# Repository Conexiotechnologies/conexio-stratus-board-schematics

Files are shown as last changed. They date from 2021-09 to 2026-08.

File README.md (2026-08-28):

# Conexio Stratus Cellular Board Design
Here you will find the schematic designs for the Conexio Stratus IoT dev kit based on nRF91xx series and the associated shields and the expansion dock.
A detailed description of the pin mapping can be found in each specific board directory.

## nRF9151 Conexio Stratus Pro Series

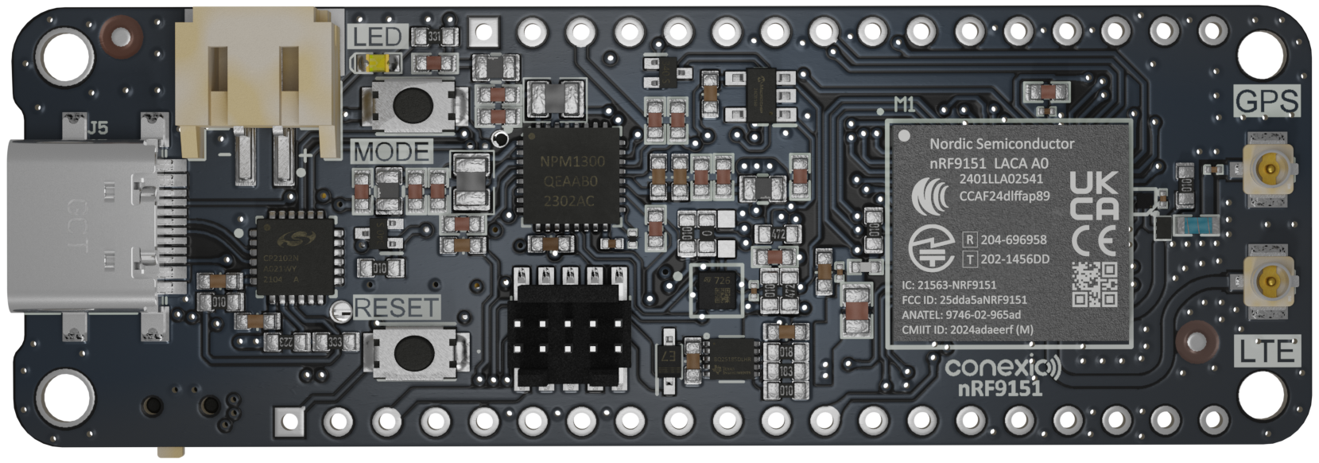
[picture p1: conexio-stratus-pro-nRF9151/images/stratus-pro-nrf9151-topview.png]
Stratus Pro - nRF9161/nRF9151


**Conexio Stratus Pro** is a tiny-yet-powerful development kit for creating cellular-connected electronic projects and products. Powered by the cutting-edge nRF9161 cellular modem from Nordic Semiconductor, Stratus Pro offers unparalleled versatility, reliability, and ease of use, making it the go-to solution for IoT developers worldwide. It is a battery-operated platform, making it ideal for prototyping cellular IoT systems, such as asset tracking, environmental monitoring, smart metering, and even industrial automation.

With LTE-M, NB-IoT, and GPS connectivity packed into a compact form factor, Stratus Pro ensures your devices stay connected in any environment. It enables real-time data transmission and location tracking with minimal power consumption. Future-proof your IoT projects with DECT NR+ readiness, ensuring compatibility with emerging cellular standards for enhanced performance and longevity.

## Built-In Battery Charging, Monitoring and Energy-Harvesting

Thanks to the nPM1300 PMIC and fuel gauge, you can remotely monitor your Stratus Pro’s battery vitals and charging status. Stratus Pro also has built-in charging circuitry that makes it easier to connect to and recharge the Li-Po battery, creating fully energy-autonomous applications.

## Conexio Stratus Pro nRF9151 Pinouts

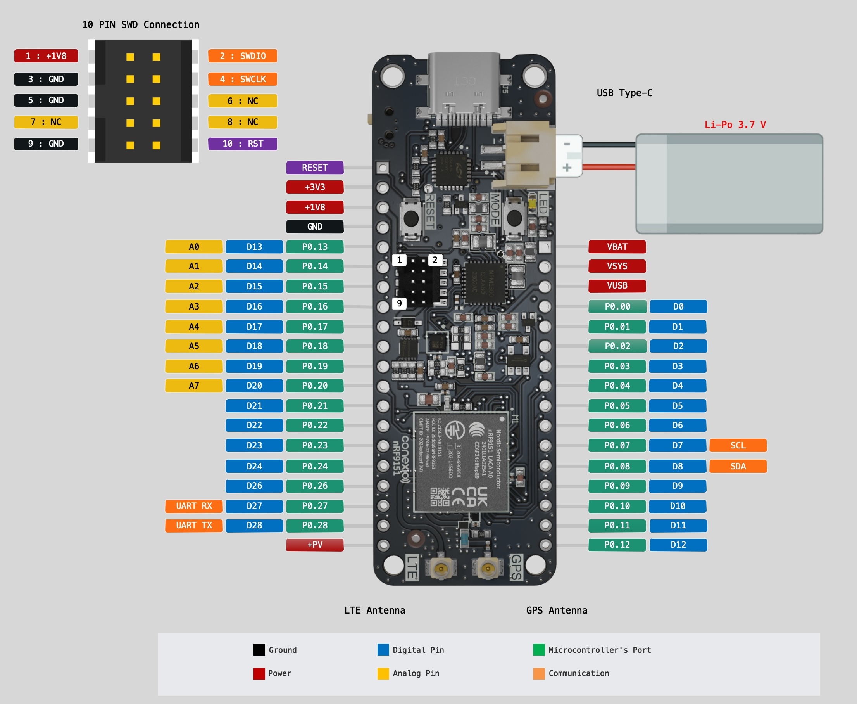
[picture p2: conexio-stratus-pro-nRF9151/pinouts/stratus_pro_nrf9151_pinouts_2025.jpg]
Stratus Pro nRF9151 Pinouts


## Features & Specifications

**MCU**: Nordic nRF9151 Microcontroller 
- ARM Cortex-M33 with 1 MB Flash
- 256 kB RAM
- Pre-programmed MCUBoot bootloader

**Modem**
- Transceiver and baseband
- 3GPP LTE release 14 LTE-M/NB-IoT support
- DECT NR+ ready
- GPS/GNSS receiver
- RF Transceiver for global coverage supporting bands:
- B1, B2, B3, B4, B5, B8, B12, B13, B17, B18, B19, B20, B25, B26, B28, B65 (new), B66, and B85 (new)
- Supports 4FF Nano SIM, optional eSIM, or software SIM

**Included cellular Data**
- 500 MB of cellular data
- 250 SMS messages
- Valid for 10 years, can be reloaded or moved to a new plan
- Service available in 100+ countries (LTE + NB-IoT)

**Power Management IC: Nordic nPM1300**
- 800 mA battery charger
- Dual 200 mA buck DC/DC regulator
- Charging IC: Texas Instruments BQ25185
- Charge inputs: 3 V to 18 V
- Supports Li-ion, Li-Poly, and LiFePO4 battery chemistries

**External Storage**
- 16 KBit I2C EEPROM memory (24CW160T)

**Power**
- Operating range 1.8 to 5.5 V
- External LiPo battery connection (2 Pin JST type)
- Maximum output current: 800 mA
- Output voltages (via headers): 1.8 V, 3.3 V, 5 V (VUSB), VBAT
- SPDT slide switch for turning Stratus Pro on or off
- Quiescent current of entire board < 9 μA

**Onboard sensors**
- Battery fuel gauge enabled by nPM1300
- STMicroelectronics LIS2DH MEMS high-performance 3-axis accelerometer

**I/O**
- USB Type-C, for USB-to-Serial, DFU, and application firmware programming and debugging or battery charging
- 1 x U.FL for LTE-M/NB-IoT antenna
- 1 x U.FL for passive GPS antenna
- Total I/O pinouts: 36
- User I/O: Feather-compatible header, 28 programmable GPIO pins, 2 push buttons (1 reset, 1 programmable), 1 programmable LED
- QWIIC connector for external peripherals
- Supports J-Link and CMSIS-DAP-based programmers
- Onboard 10-pin 0.05 " (1.27 mm) mini SWD/JTAG pin connector

**Size**
- 66.04 mm x 25.40 mm

## Stratus Pro Expansion Dock

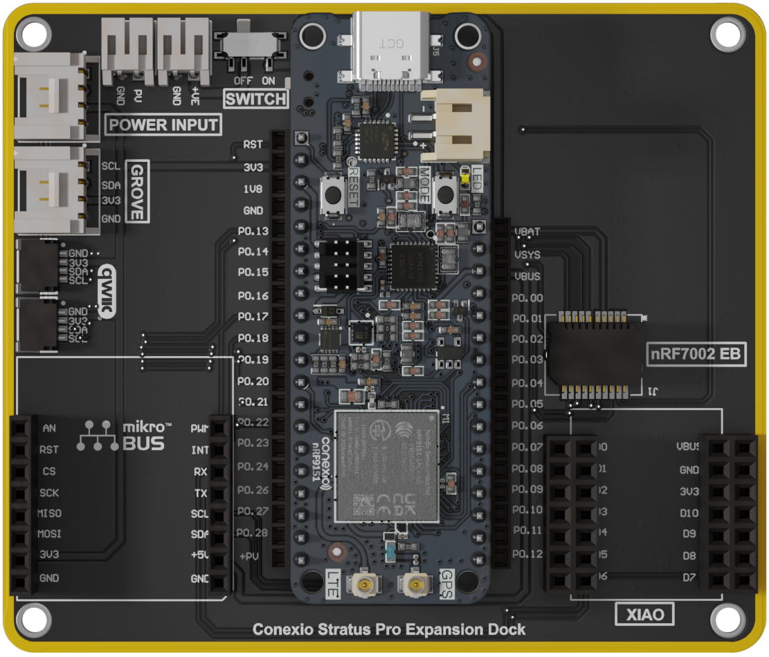
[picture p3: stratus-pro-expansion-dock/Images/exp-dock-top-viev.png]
Expansion Dock


Start your product development with our Expansion Dock for Stratus Pro fast and easy. The Expansion Dock offers two QWIIC connectors, two Grove sockets, a mikroBUS™ socket, an nRF7002 Expansion board socket to add Wi-Fi location capabilities, and a SeeedStudio Xiao socket allowing you to create various wireless applications with one host board. It can't get any better than this., working with a Stratus shield requires no soldering and minimal wiring. Just plug the sensors, actuators, or displays into this shield via the standard cables, and focus on coding and application creation.

## Features & Specifications

- 2 x Stratus Pro nRF9151/nRF9161 header sockets.
- 1 x nRF7002EB socket.
- 1 x SeeedStudio Xiao socket.
- 1 x mikro BUS: add-on board standard from Mikroe, allowing connection to over 800+ click boards.
- 2 x Sparkfun Qwiic connector: SparkFun's Qwiic Connect System, allowing to connect over 100+ Qwiic products.
- 2 x Grove I2C connector: Grove is a modular, standardized connector prototyping system by Seeedstudio.
- 1 x 2 Pin JST connector for plugging the solar panel input.
- 1 x 2 Pin JST connector for plugging the lipo battery.
- 1 x Power switch

## Purchase

Conexio Stratus devices and accessories can be purchased directly from our [online store](https://conexiotech.com/shop/).

Please contact [info@conexiotech.com](mailto:info@conexiotech.com) if you would like to arrange help with your manufacturing and custom PCB design based on Stratus Pro platform. 

Copyright (c) 2025 Conexio Technologies, Inc.

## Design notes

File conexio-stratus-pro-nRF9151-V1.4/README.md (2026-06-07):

# Conexio Stratus Pro nRF9151-LACA-A1A V1.4

**Conexio Stratus Pro** is a tiny-yet-powerful development kit for creating cellular-connected electronic projects and products. Powered by the cutting-edge nRF9151 cellular modem from Nordic Semiconductor, Stratus Pro offers unparalleled versatility, reliability, and ease of use, making it the go-to solution for IoT developers worldwide. It is a battery-operated platform, making it ideal for prototyping cellular IoT systems, such as asset tracking, environmental monitoring, smart metering, and even industrial automation.

With LTE-M, NB-IoT, DECT NR+, NTN, and GPS connectivity packed into a compact form factor, Stratus Pro ensures your devices stay connected in any environment. It enables real-time data transmission and location tracking with minimal power consumption. Future-proof your IoT projects with DECT NR+ readiness, ensuring compatibility with emerging cellular standards for enhanced performance and longevity.

## Built-In Battery Charging, Monitoring and Energy-Harvesting

Thanks to the nPM1300 PMIC and fuel gauge, you can remotely monitor your Stratus Pro’s battery vitals and charging status. Stratus Pro also has built-in charging circuitry that makes it easier to connect to and recharge the Li-Po battery, creating fully energy-autonomous applications.

## Conexio Stratus Pro nRF9151 Pinouts

[Stratus Pro nRF9151 Pinouts](https://docs.conexiotech.com/master/stratus-overview/stratus-pro-nrf9151-pin-diagram)

## Features & Specifications

**MCU**: Nordic nRF9151 Microcontroller 
- ARM Cortex-M33 with 1 MB Flash
- 256 kB RAM
- Pre-programmed MCUBoot bootloader

**Modem**
- Transceiver and baseband
- 3GPP LTE release 14 LTE-M/NB-IoT support
- DECT NR+ ready
- NTN ready
- GPS/GNSS receiver
- RF Transceiver for global coverage supporting bands:
- B1, B2, B3, B4, B5, B8, B12, B13, B17, B18, B19, B20, B25, B26, B28, B65 (new), B66, and B85 (new)
- Supports 4FF Nano SIM, optional eSIM, or software SIM

**Power Management IC: Nordic nPM1300**
- 800 mA battery charger
- Dual 200 mA buck DC/DC regulator
- Charging IC: Texas Instruments BQ25185
- Charge inputs: 3 V to 18 V
- Supports Li-ion, Li-Poly, and LiFePO4 battery chemistries

**Power**
- Operating range 1.8 to 5.5 V
- External LiPo battery connection (2 Pin JST type)
- Maximum output current: 800 mA
- Output voltages (via headers): 1.8 V, 3.3 V, 5 V (VUSB), VBAT
- SPDT slide switch for turning Stratus Pro on or off
- Quiescent current of entire board < 9 μA

**Onboard sensors and storage**
- Battery fuel gauge enabled by nPM1300
- 16 KBit I2C EEPROM memory (24CW160T)

**I/O**
- USB Type-C, for USB-to-Serial, DFU, and application firmware programming and debugging or battery charging
- 1 x U.FL for LTE-M/NB-IoT antenna
- 1 x U.FL for passive GPS antenna
- Total I/O pinouts: 36
- User I/O: Feather-compatible header, 28 programmable GPIO pins, 2 push buttons (1 reset, 1 programmable), 1 programmable LED, 1x RGB LED
- QWIIC connector for external peripherals
- Supports J-Link and CMSIS-DAP-based programmers
- Onboard 10-pin 0.05 " (1.27 mm) mini SWD/JTAG pin connector

**Size**
- 67.04 mm x 22 mm

## Hardware Revision Changes V1.4 (2026)
**Addition**
- RGB LED to NPM1300
- Hardware jumper for voltage selection (1.8V/3.3V)

**Removed**
- LIS2DH sensor

**Bug**
- Fixed backpower introduced by the CP2102N chipset when USB is connected

## Purchase

Conexio Stratus devices and accessories can be purchased directly from our [online store](https://conexiotech.com/shop/).

Please contact [info@conexiotech.com](mailto:info@conexiotech.com) if you would like to arrange help with your manufacturing and custom PCB design based on Stratus Pro platform. 

## Hardware Lineage and License

This board is released under the [CERN OHL-P (v2) license](https://opensource.org/license/cern-ohl-p). See LICENSE for more info.

Copyright (c) 2026 Conexio Technologies, Inc.

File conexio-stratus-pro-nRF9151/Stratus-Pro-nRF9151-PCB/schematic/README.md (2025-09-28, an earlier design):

# nRF9151 Conexio Stratus Pro Board Schematics
Here you will find the schematic design for the Conexio Stratus Pro IoT dev kit based on nRF9151 SiP.

Copyright (c) 2025 Conexio Technologies, Inc.

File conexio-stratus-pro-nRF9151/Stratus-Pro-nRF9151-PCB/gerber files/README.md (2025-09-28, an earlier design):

# Stratus Pro Gerber Files

Copyright (c) 2025 Conexio Technologies, Inc.

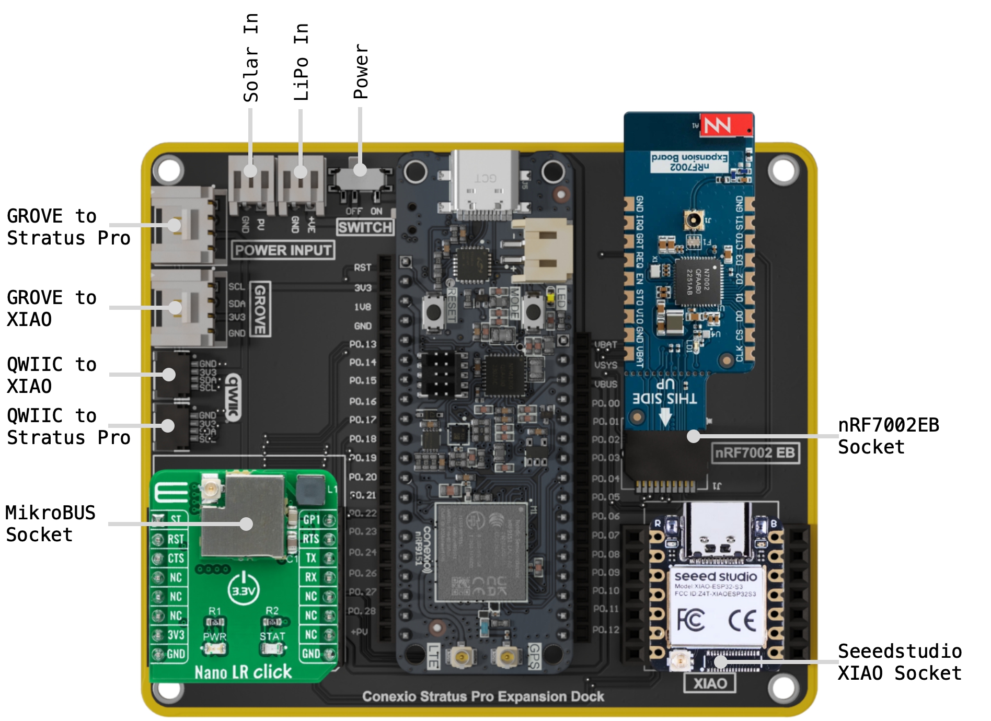
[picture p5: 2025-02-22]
stratus-pro-expansion-dock/Images/expansion_dock_pinouts.jpg

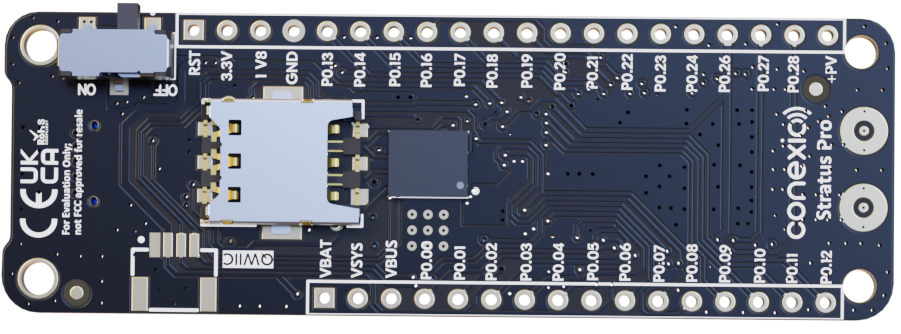
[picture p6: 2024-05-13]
conexio-stratus-pro-nRF9161/images/stratus-pro-nRF9161-bottom-view.png

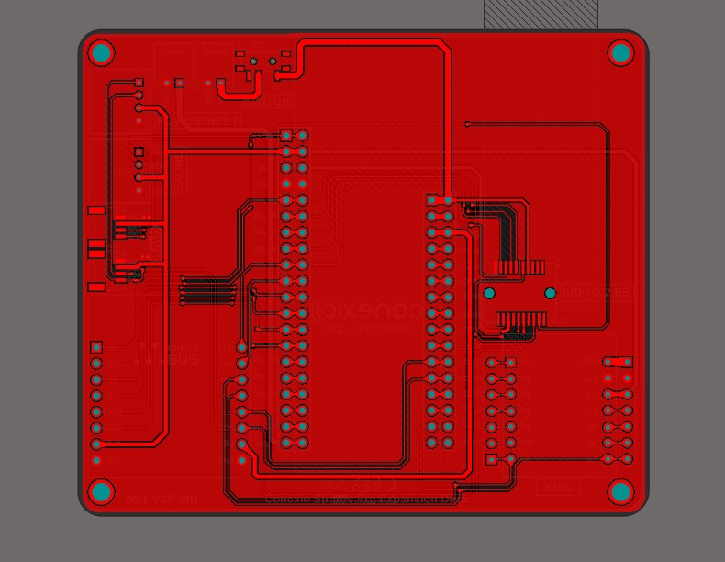
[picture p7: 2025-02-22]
stratus-pro-expansion-dock/Images/2D top.jpg

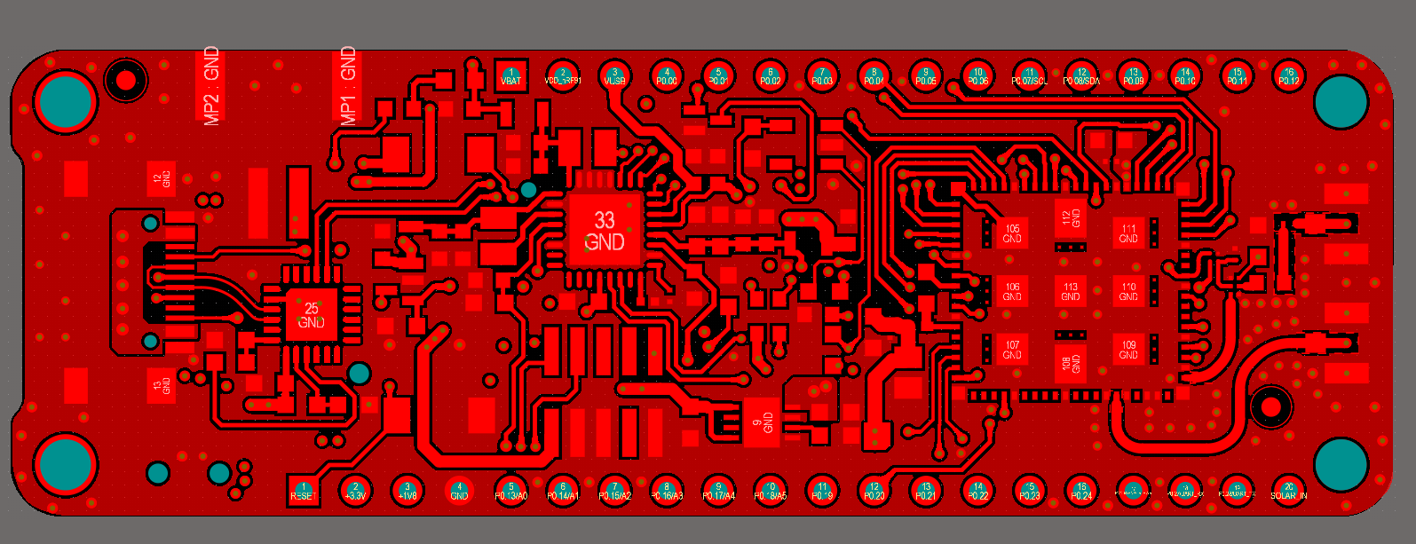
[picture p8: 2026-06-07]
conexio-stratus-pro-nRF9151-V1.4/Images/2D Top.png

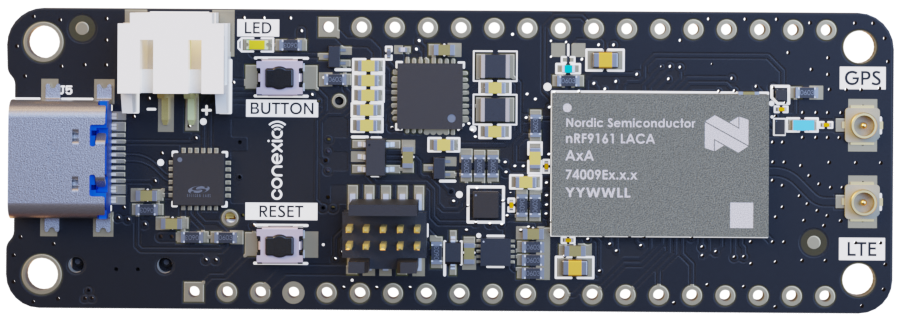
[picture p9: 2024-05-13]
conexio-stratus-pro-nRF9161/images/stratus-pro-nRF9161-top-view.png

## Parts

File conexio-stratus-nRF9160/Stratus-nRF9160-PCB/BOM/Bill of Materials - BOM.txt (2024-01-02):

Qty Value                                              Device                                             Package                   Parts                             Description                                                                                                      
1                                                      CONN_01                                            1X01                      J9                                Single connection point. Often used as Generic Header-pin footprint for 0.1 inch spaced/style header connections 
2   0.1u                                               CAP-0.1U-50V-0402                                  CAPC1005X55N              C10, C18                          CAPACITOR                                                                                                        
8   100k                                               RES-100K-1%-0402                                   R0402-M                   R1, R2, R3, R7, R8, R10, R13, R20 RESISTOR                                                                                                         
2   10k                                                RES-20K-1%-0402                                    R0402-M                   R17, R18                          RESISTOR                                                                                                         
2   10uF                                               C0603_10UF                                         C0603                     C15, C16               	 Non-polarized capacitor                                                                                          
1   10uH                                               L0603_10UH                                         L0603                     L3                                Inductor                                                                                                         
1   10uH-0.55A                                         L3.9X3.9_10UH_0.55A                                LPS4012                   L5                                Inductor                                                                                                         
2   15p                                                CAP-15P-50V-0402                                   CAPC1005X55N              C1, C2                            CAPACITOR                                                                                                        
1   1M                                                 RES-1M-5%-0402                                     R0402-M                   R9                                RESISTOR                                                                                                         
1   1k                                                 RES-100K-1%-0402                                   R0402-M                   R6                                RESISTOR                                                                                                         
2   1u                                                 CAP-1U-25V-1-0402                                  CAPC1005X55N              C11, C13                          CAPACITOR                                                                                                        
1   22k                                                RES-100K-1%-0402                                   R0402-M                   R15                               RESISTOR                                                                                                         
3   22uF                                               CAP-10U-6.3V-0603                                  C0603                     C4, C5, C7                        CAPACITOR                                                                                                        
1   22uF 10V                                           C0603_22UF                                         C0603                     C14                               Non-polarized capacitor                                                                                          
1   2k                                                 RES-3.4K-1%-0402                                   R0402-M                   R12                               RESISTOR                                                                                                         
2   330                                                RES-330-5%-0402                                    R0402-M                   R11, R14                          RESISTOR                                                                                                         
1   33k                                                RES-100K-1%-0402                                   R0402-M                   R16                               RESISTOR                                                                                                         
1   39n                                                IND-39NH-250MA-0402                                IND0402_22N_TAI           L1                                INDUCTOR                                                                                                         
3   4.7u                                               CAP-4.7U-6.3V-2-0603                               C0603                     C3, C8, C9                        CAPACITOR                                                                                                        
2   4.7uF                                              CAP-1U-25V-1-0402                                  CAPC1005X55N              C6, C20                           CAPACITOR                                                                                                        
2   5.1k                                               5.1KOHM-0402T-1/16W-1%                             0402-TIGHT                R22, R23                                                                                                                                           
1   511k                                               RES-100K-1%-0402                                   R0402-M                   R4                                RESISTOR                                                                                                         
2   56p                                                CAP-56PF-50V-1-0402                                CAPC1005X55N              C12, C19                          CAPACITOR                                                                                                        
1   68n                                                IND-68NH-200MA-0402                                IND0402_22N_TAI           L4                                INDUCTOR                                                                                                         
1   91k                                                RES-100K-1%-0402                                   R0402-M                   R5                                RESISTOR                                                                                                         
1   AEM10941                                           AEM10941                                           QFN50P505X505X90-28       IC3                               Ambient Energy Manager from e-peas                                                                               
1   CL-SB-12B-11T                                      CL-SB-12B-11T                                      CLSB12B01T                S2                                NIDEC COPAL ELECTRONICS - CL-SB-12B-11T - SLIDE SWITCH, SPDT, 0.2A, 12VDC, SMD                                   
2   CON-1909763-1                                      CON-1909763-1                                      TE_1909763-1              J4, J7                            VAO ITEM, MINI RF HEADER                                                                                         
2   CON-HEADER-1X16-MALE-PIN                           CON-HEADER-1X16-MALE-PIN                           CON-HEADER-1X16-MALE-PIN  J2, J3                                                                                                                                             
1   CON-S2B-PH-SM4-TB(LF)(SN)                          CON-S2B-PH-SM4-TB(LF)(SN)                          JST_S2B-PH-SM4-TB(LF)(SN) J6                                PH Series 2 Position 2 mm Pitch Surface Mount Side Entry Shrouded Header                                         
1   CON-SIM-104224-0820                                CON-SIM-104224-0820                                MOLEX_104224-0820         J5                                Conn SIM SKT 6 POS 2.54mm Solder RA SMD                                                                          
1   DFE201612E-1R0M=P2                                 WE-PMCI_0806_74479276124                           WE-PMCI_0806              L6                                WE-PMCI Power Molded Chip Inductor                                                                               
1   DMP2160UW                                          MOSFET-P-CHANNEL-DMP2160UW                         SOT323                    Q5                                MOSFET P Channel                                                                                                 
1   FTSH-105-01-LM-DV-K                                FTSH-105-01-LM-DV-K                                FTSH-105-XX-YYY-DV-K      J8                                10 Position, High Reliability Header Strips, 0.050" pitch                                                        
1   IC-CP2102N-A02-GQFN24R                             IC-CP2102N-A02-GQFN24R                             QFN50P400X400X80-25N      U3                                Check prices                                                                                                     
1   IC-LIS2DH12TR                                      IC-LIS2DH12TR                                      PQFN50P200X200100-12N     U10                               ACCEL 2-16G I2C/SPI 12LGA                                                                                        
1   JUMPER-NC                                          JUMPER-NC                                          JUMPER-ROUND-NC           JMP1                                                                                                                                               
1   LED-BLUE-0402                                      LED-BLUE-0402                                      LED_EAST1005              D3                                                                                                                                                 
1   MCP73831                                           MCP73831                                           SOT23-5                   U2                                MCP73831T Li-Ion, Li-Pol Controller                                                                              
1   MOD-NRF9160-SICA-R                                 MOD-NRF9160-SICA-R                                 NORDIC_NRF9160-SICA-R     U1                                NRF9160-SICA-R                                                                                                   
1   MOSFET-DUAL-COMP-SOT563                            MOSFET-DUAL-COMP-SOT563                            SOT50P160X60-6N           Q2                                                                                                                                                 
1   MOSFET-N-SC89                                      MOSFET-N-SC89                                      DIO_RB558WMF-L            Q4                                                                                                                                                 
1   MOSFET-P-20V-4.7A-SOT23                            MOSFET-P-20V-4.7A-SOT23                            SOT23                     Q3                                MOSFET P-CH                                                                                                      
2   PMEG1030EJ,115                                     DIODESOD-323F                                      SOD-323F                  D1, D5                            Diode                                                                                                            
1   POWER-SWITCH-MIC94092YC6                           POWER-SWITCH-MIC94092YC6                           SOT363                    U4                                IC SWITCH                                                                                                        
1   SENSIRION_SHT40-AD1B-R2SENSIRION_SHT40-AD1B-R2_0_0 SENSIRION_SHT40-AD1B-R2SENSIRION_SHT40-AD1B-R2_0_0 SENSIRION_SHT40-AD1B-R2_0 IC2                               Humidity Temperature Sensor 0 ~ 100% RH Digital ±1.8% RH Surface Mount                                           
2   SW-EVP-AA402W                                      SW-EVP-AA402W                                      SW-EVP-AA402W             SW1, SW2                                                                                                                                           
1   TPS63802DLARTEXAS_INSTRUMENTS_TPS63802DLAR_0_0     TPS63802DLARTEXAS_INSTRUMENTS_TPS63802DLAR_0_0     TPS63802DLAR              U6                                2-A, High-efficient, Low IQ Buck-boost Converter in DFN Package                                                  
1   USB Female C                                       USB_C_4-LAYER_PADS                                 USB-C-16P_4LAYER-PADS     J10                               USB Type C 16Pin Connector                                                                                       
1   Yellow                                             LED-ORANGE-0402                                    LED_EAST1005              D4

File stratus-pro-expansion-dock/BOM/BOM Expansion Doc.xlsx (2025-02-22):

Comment | Description | Designator | Footprint | LibRef | Quantity
L200HY-W-2A |  | BAT, PV | CONN-TH_L200HY-W-2A | L200HY-W-2A | 2
10056847-101LF | No Description Available | J1 | CONN_10056847-101LF_AMP | 10056847-101LF | 1
110990037 | 110990037 Grove Female Header - DIP-4P-2.0mm-90D-10 Pcs | J2, J3 | FP-110990037-MFG | CMP-03859-66366633-1 | 2
Header 20X2 | Header, 20-Pin, Dual row | P1 | HDR2X20 | Header 20X2 | 1
Header 16X2 | Header, 16-Pin, Dual row | P2 | HDR2X16 | Header 16X2 | 1
ESP32 S3 XIAO |  | P3 | HDR2X7 | Header 7X2 | 1
Header 7 | Header, 7-Pin | P6, P8 | HDR1X7 | Header 7 | 2
Header 8X2A | Header, 8-Pin, Dual row | P7 | HDR2X8_CEN | Header 8X2A | 1
C2764183 |  | QWIIC, QWIIC1 | C2764183 | C2764183 | 2
MSK12CO2-SZ |  | SW1 | SW-TH_MSK12C02 | MSK12CO2-SZ | 1
AFC10-S04QCA-00 |  | X1, X2 | CONN-SMD_AFC10-S04QCA-00 | AFC10-S04QCA-00 | 2

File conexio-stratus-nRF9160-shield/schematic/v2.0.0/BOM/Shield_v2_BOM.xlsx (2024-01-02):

Part | Qty | Value | Device | Package | DESCRIPTION | DIGI-KEY_PART_NUMBER | Comments | comments
HEAD1,HEAD4 | 2 | HEADER_17PIN | HEADER_17PIN | HEADER_17PIN_2.54MM | CON-HEADER-1X17-FEMALE-PIN_2.54MM
HEAD2,HEAD3 | 2 | HEADER_16PIN | HEADER_16PIN | HEADER_16_PIN | CON-HEADER-1X16-FEMALE-PIN_2.54MM
J11 | 2 | HEADER_8PIN | HEADER_8PIN | HEADER_8_PIN | CON-HEADER-1X8-FEMALE-PIN_2.54MM
J1, J2 | 2 | ZIO-102115 | SM04B-SRSS-TB(LF)(SN) | JST_SM04B-SRSS-TB(LF)(SN) | ZIO QWIIC JST CONNECTOR BLACK 4P | 3099-ZIO-102115TR-ND
J3 | 1 | 110990037 | 11099003790D | HW4-2.0-90D | GROVE 2MM 4PIN R/A CONN | 1597-1083-ND |  | (This part comes in 10 pieces, so just $2.180, not $10.90)
J4 | 1 | S2B-PH-SM4-TB(LF)(SN) | S2B-PH-SM4-TB(LF)(SN) | JST_S2B-PH-SM4-TB(LF)(SN) | Connector Header Surface Mount, Right Angle 2 position 0.079 (2.00mm) | A100080CT-ND
LED1 | 1 | LED ORANGE | LO Q976-PS-25-0-20-R18 | LED-0603 | LED ORANGE DIFFUSED 0603 SMD | 475-2486-2-ND
R1 | 1 | 330R | R-0603 | R-0603 | RES 330 OHM 5% 1/16W 0603 | 2368-SR1-0603-133-ND |  | Yes, this is OK.

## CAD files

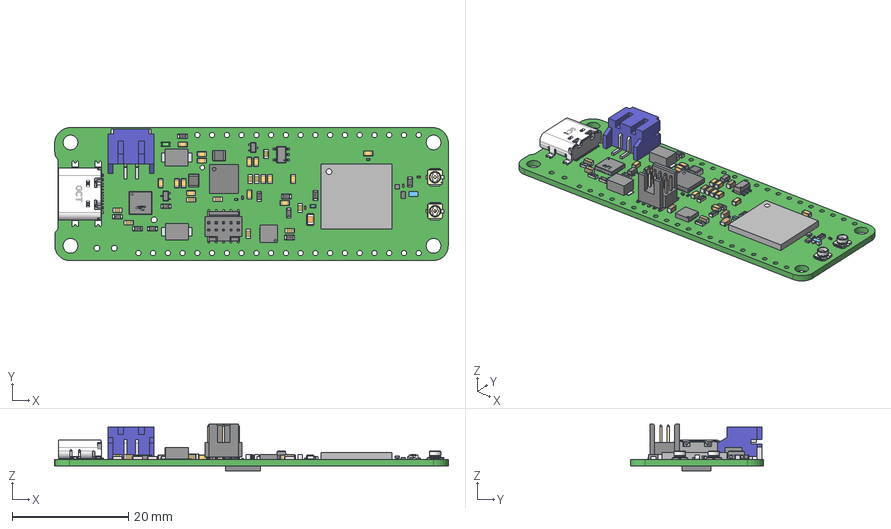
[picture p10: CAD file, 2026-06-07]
conexio-stratus-pro-nRF9151-V1.4/3D PCB/3D Model.step
67.8 x 22.9 x 8.06 mm
capacitor 0603 x 10
User Library-Chip Capacitor 0603 x 15
Extruded x 4
Pins x 2
User Library-led_0603_green
Thermal_Shape
User Library-res0201-1
User Library-0201(0603M) Cap x 4
SW3dPS-0805 SMD Capacitor
User Library-Chip Inductor 0402
User Library-INDC1608X80-MURATA_LQW18A
U.FL-R-SMT-1 x 2
Hirose Logo adjastable x 2
PinsArrayL
PinsArrayR
S2B-PH-SM4-TB
ThermalPin
PinsArrayLR
Notch
Silicon Lab Logo Yury
BD125-10-A-0305-0580-L-B
USB4110-GF-A_revB(1) MF

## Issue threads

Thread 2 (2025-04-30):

Wrong schematic in Stratus-Pro-nRF9151-PCB

advtechsol, 2025-04-30:
The schematic for the Stratus-Pro-nRF9151-PCB is actually the Stratus-Pro-nRF9161-PCB

is it possible to get the schematic for the Stratus-Pro-nRF9151-PCB?

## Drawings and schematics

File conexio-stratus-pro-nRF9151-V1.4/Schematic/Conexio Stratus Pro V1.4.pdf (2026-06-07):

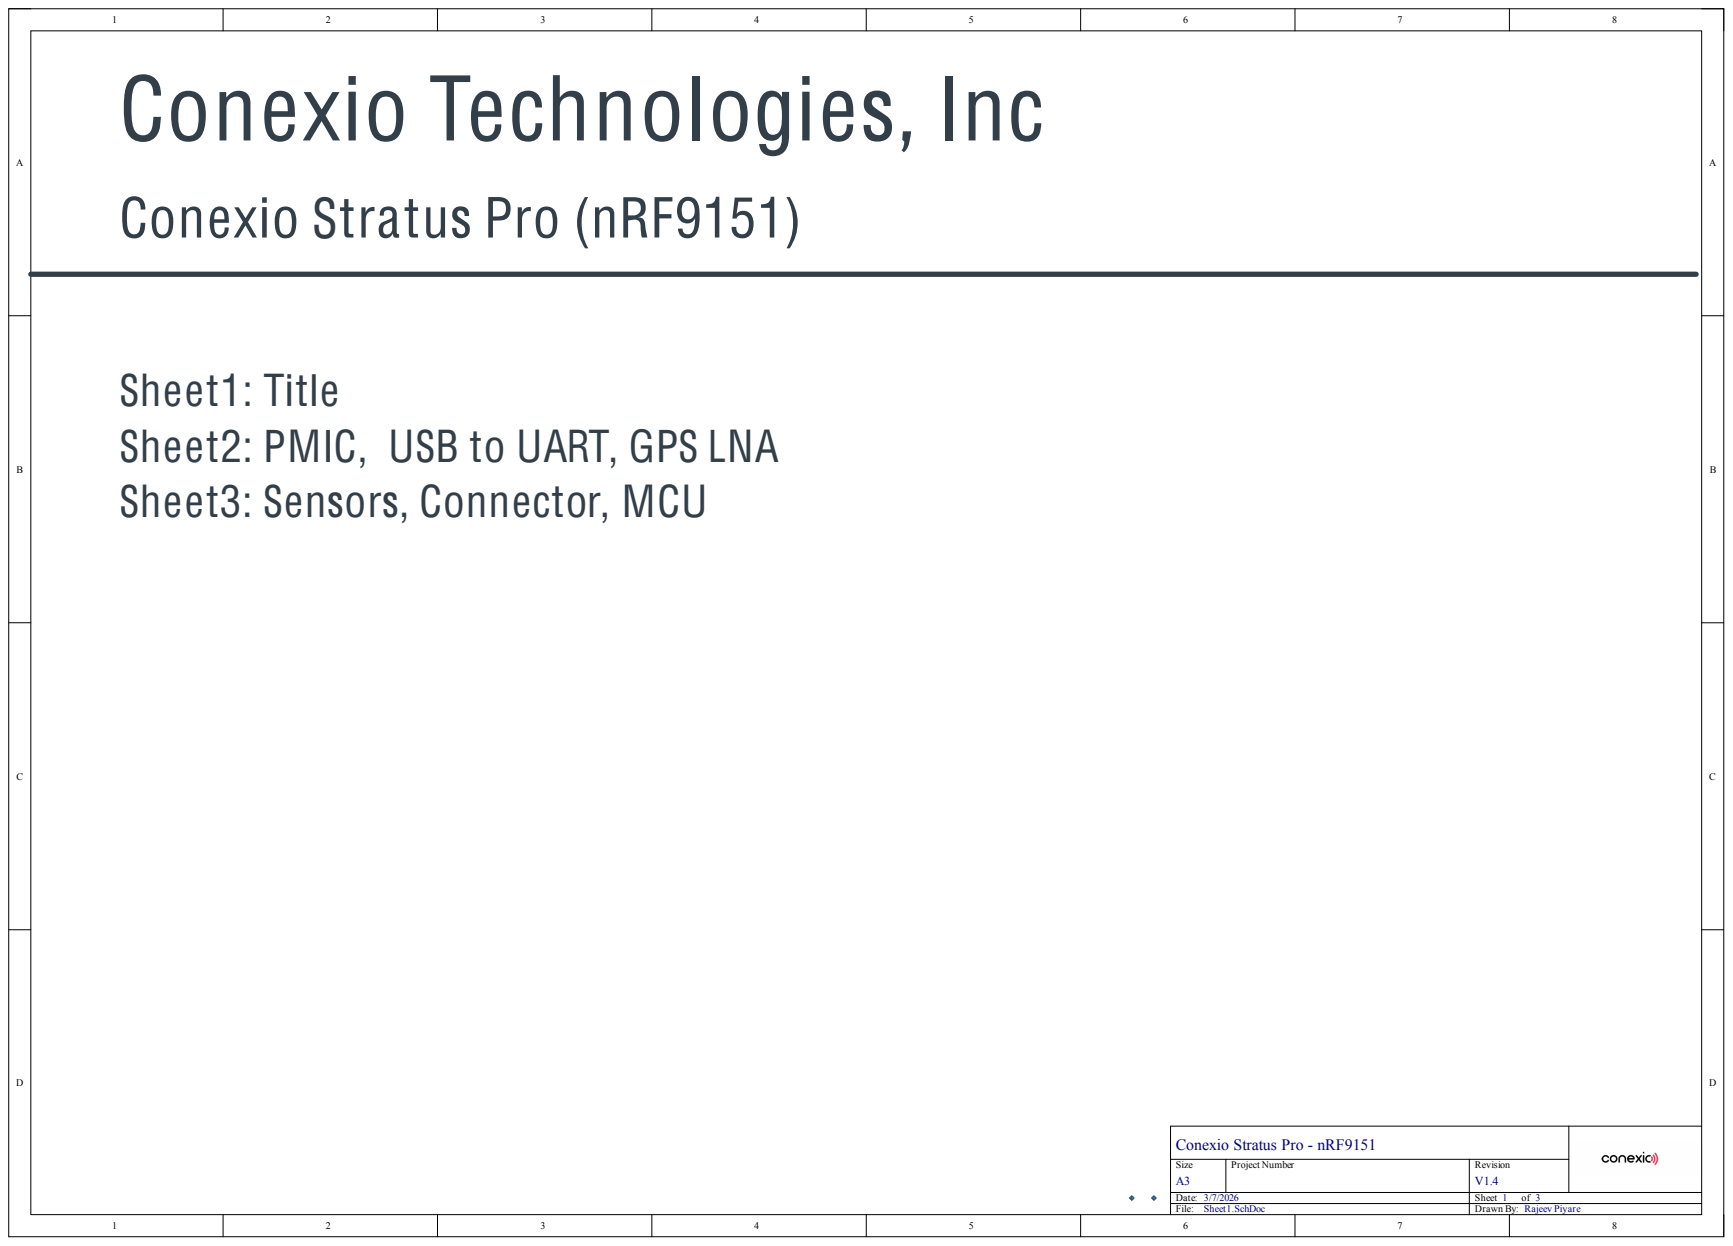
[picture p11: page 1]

Sheet1: Title
Sheet2: PMIC, USB to UART, GPS LNA
Sheet3: Sensors, Connector, MCU

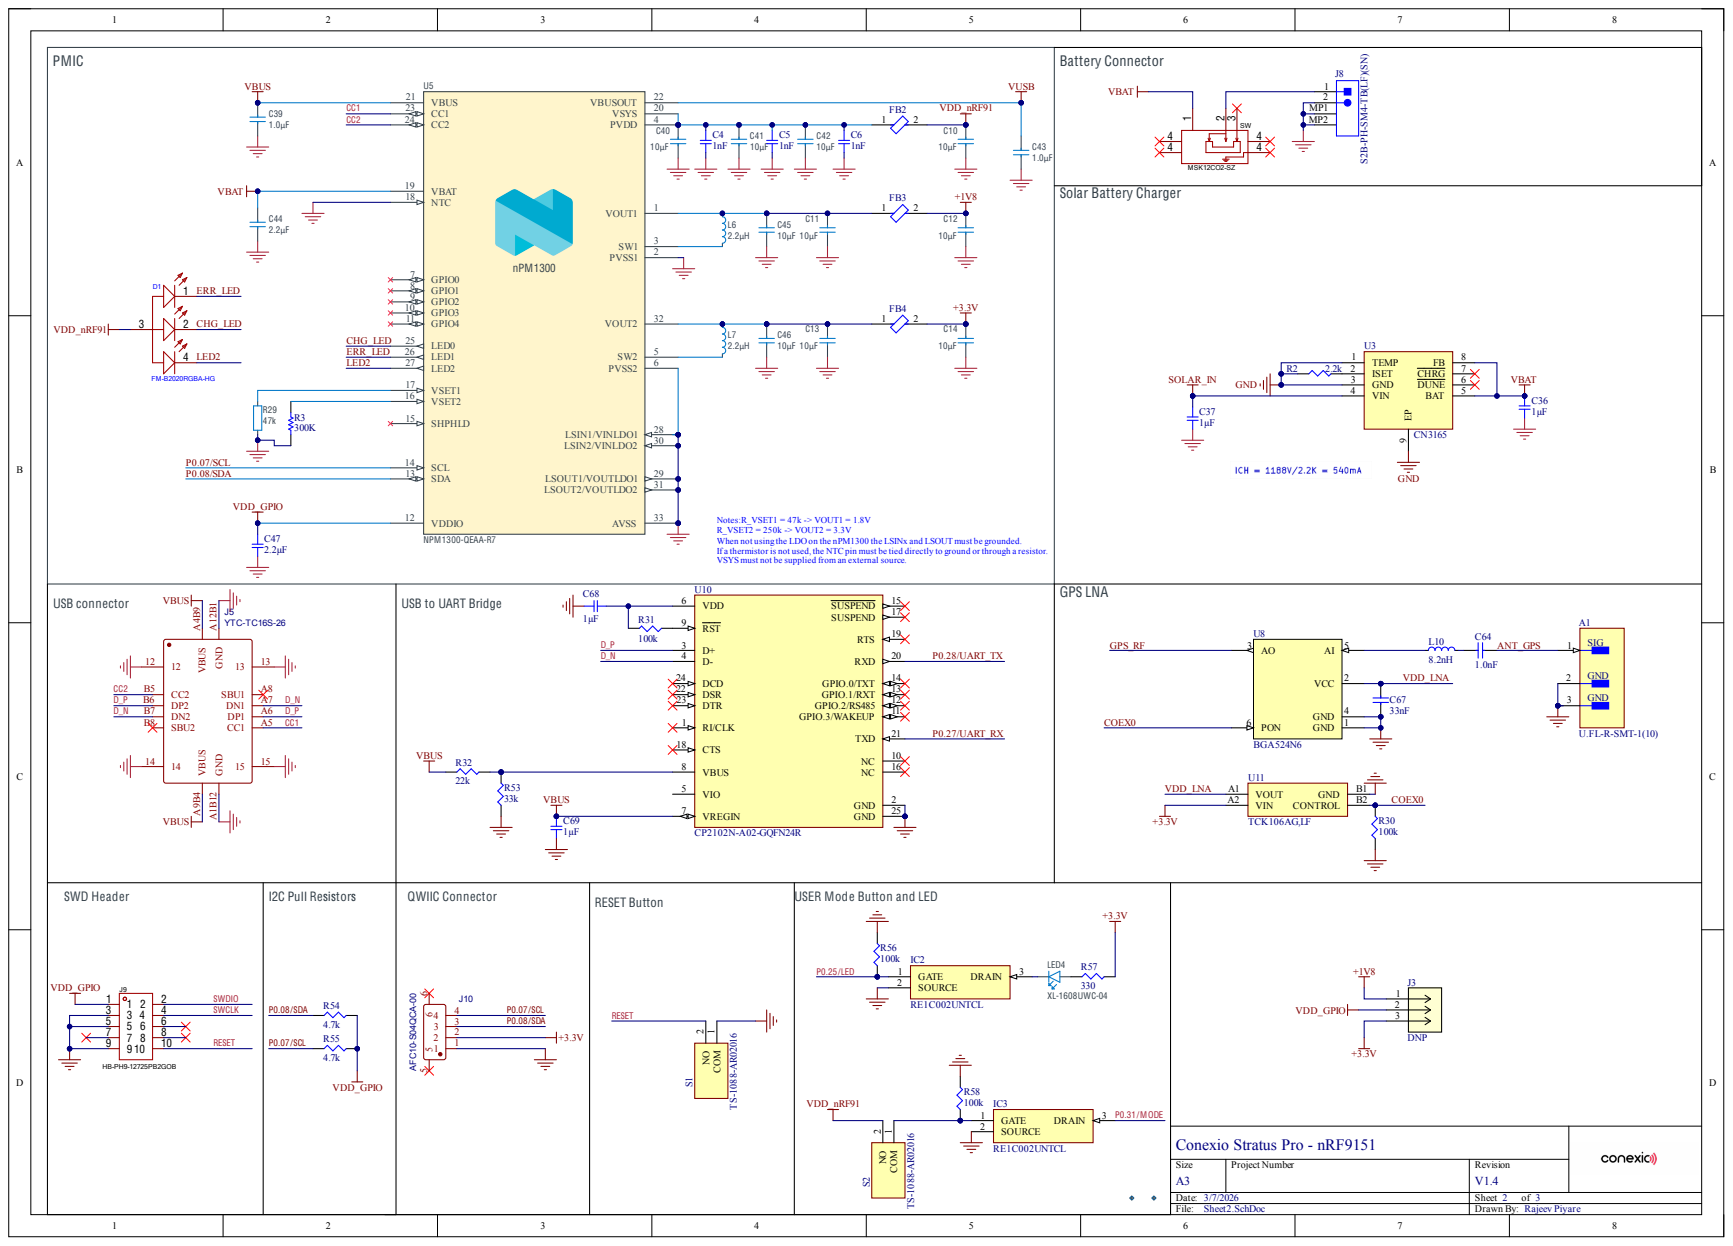
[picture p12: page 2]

Notes:R_VSET1 = 47k -> VOUT1 = 1.8V
R_VSET2 = 250k -> VOUT2 = 3.3V
When not using the LDO on the nPM1300 the LSINx and LSOUTmust be grounded.
If a thermistor is not used, the NTCpin must be tied directly to ground or through a resistor.
VSYSmust not be supplied from an external source.
GPS LNA VDD 6

USB to UART Bridge

USER Mode Button and LED

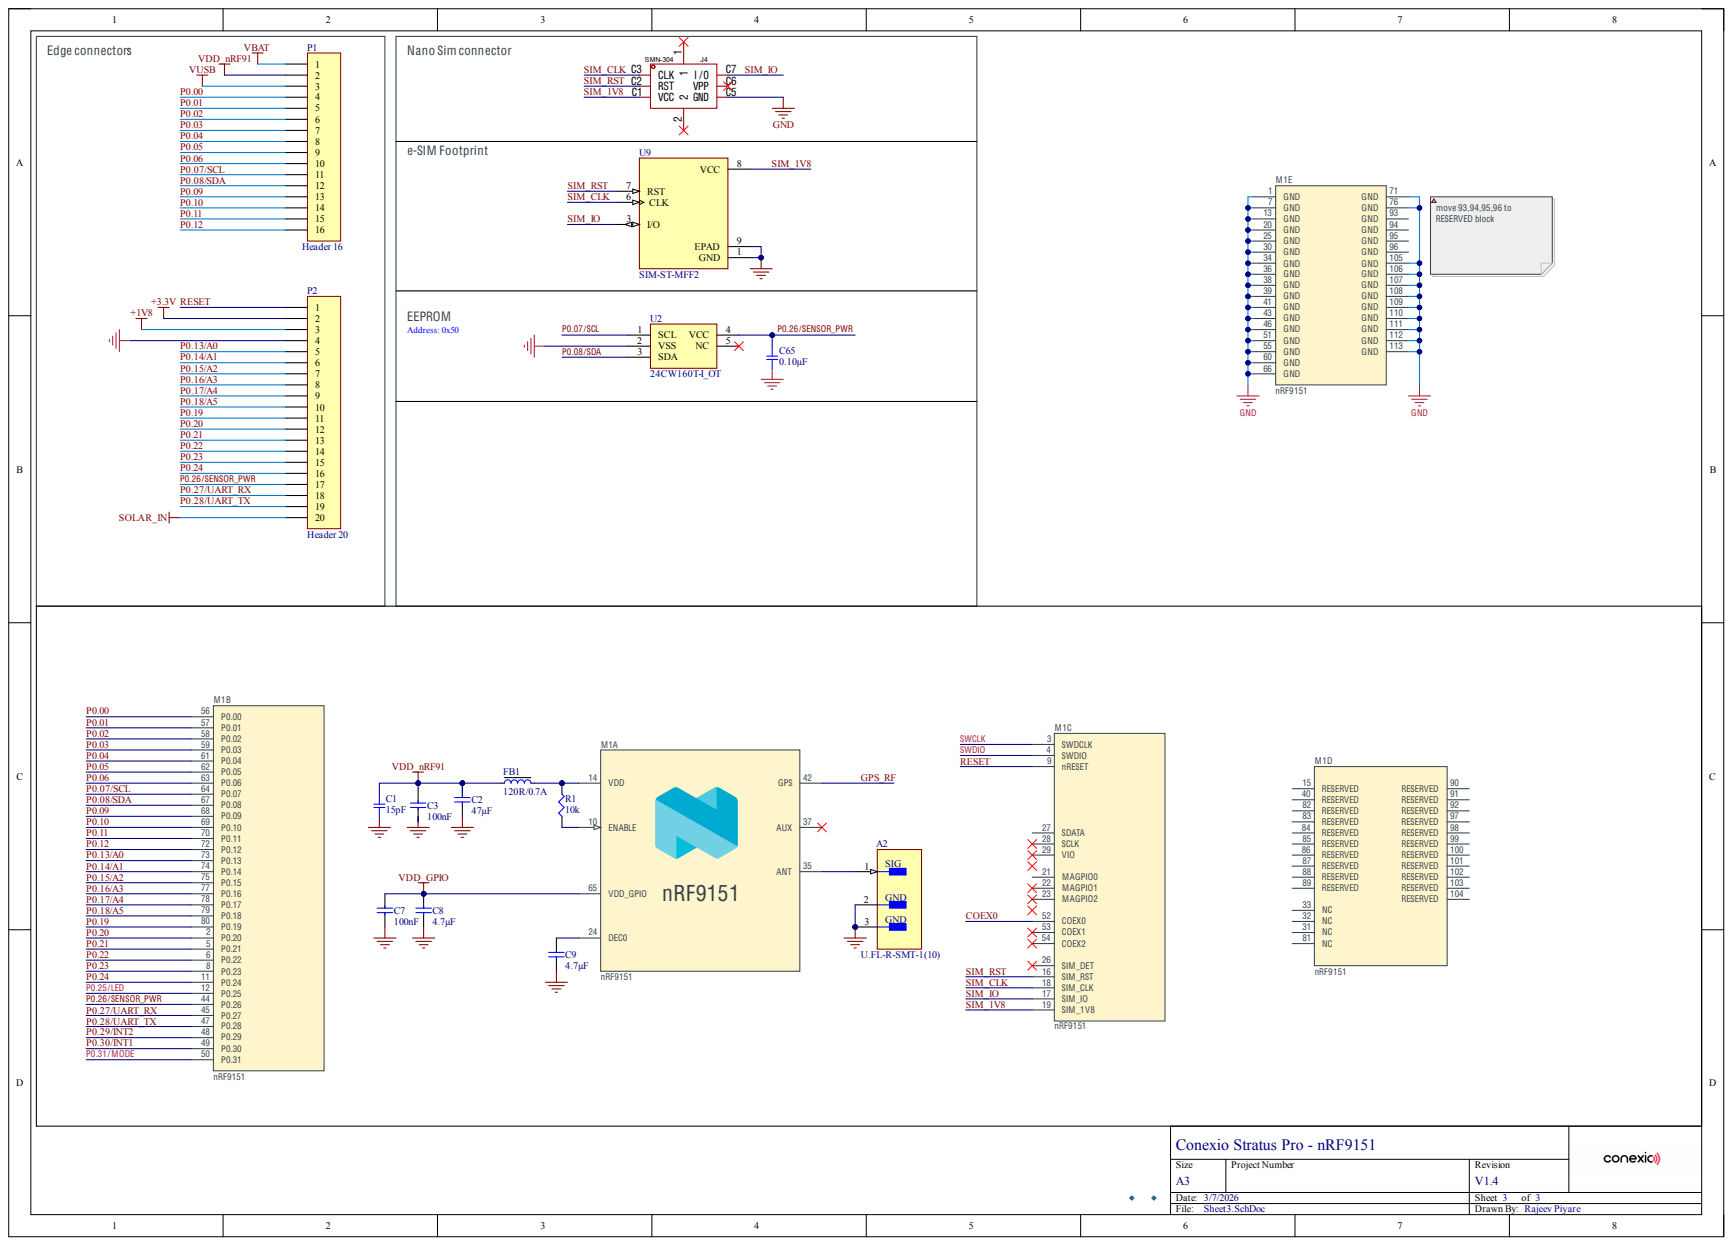
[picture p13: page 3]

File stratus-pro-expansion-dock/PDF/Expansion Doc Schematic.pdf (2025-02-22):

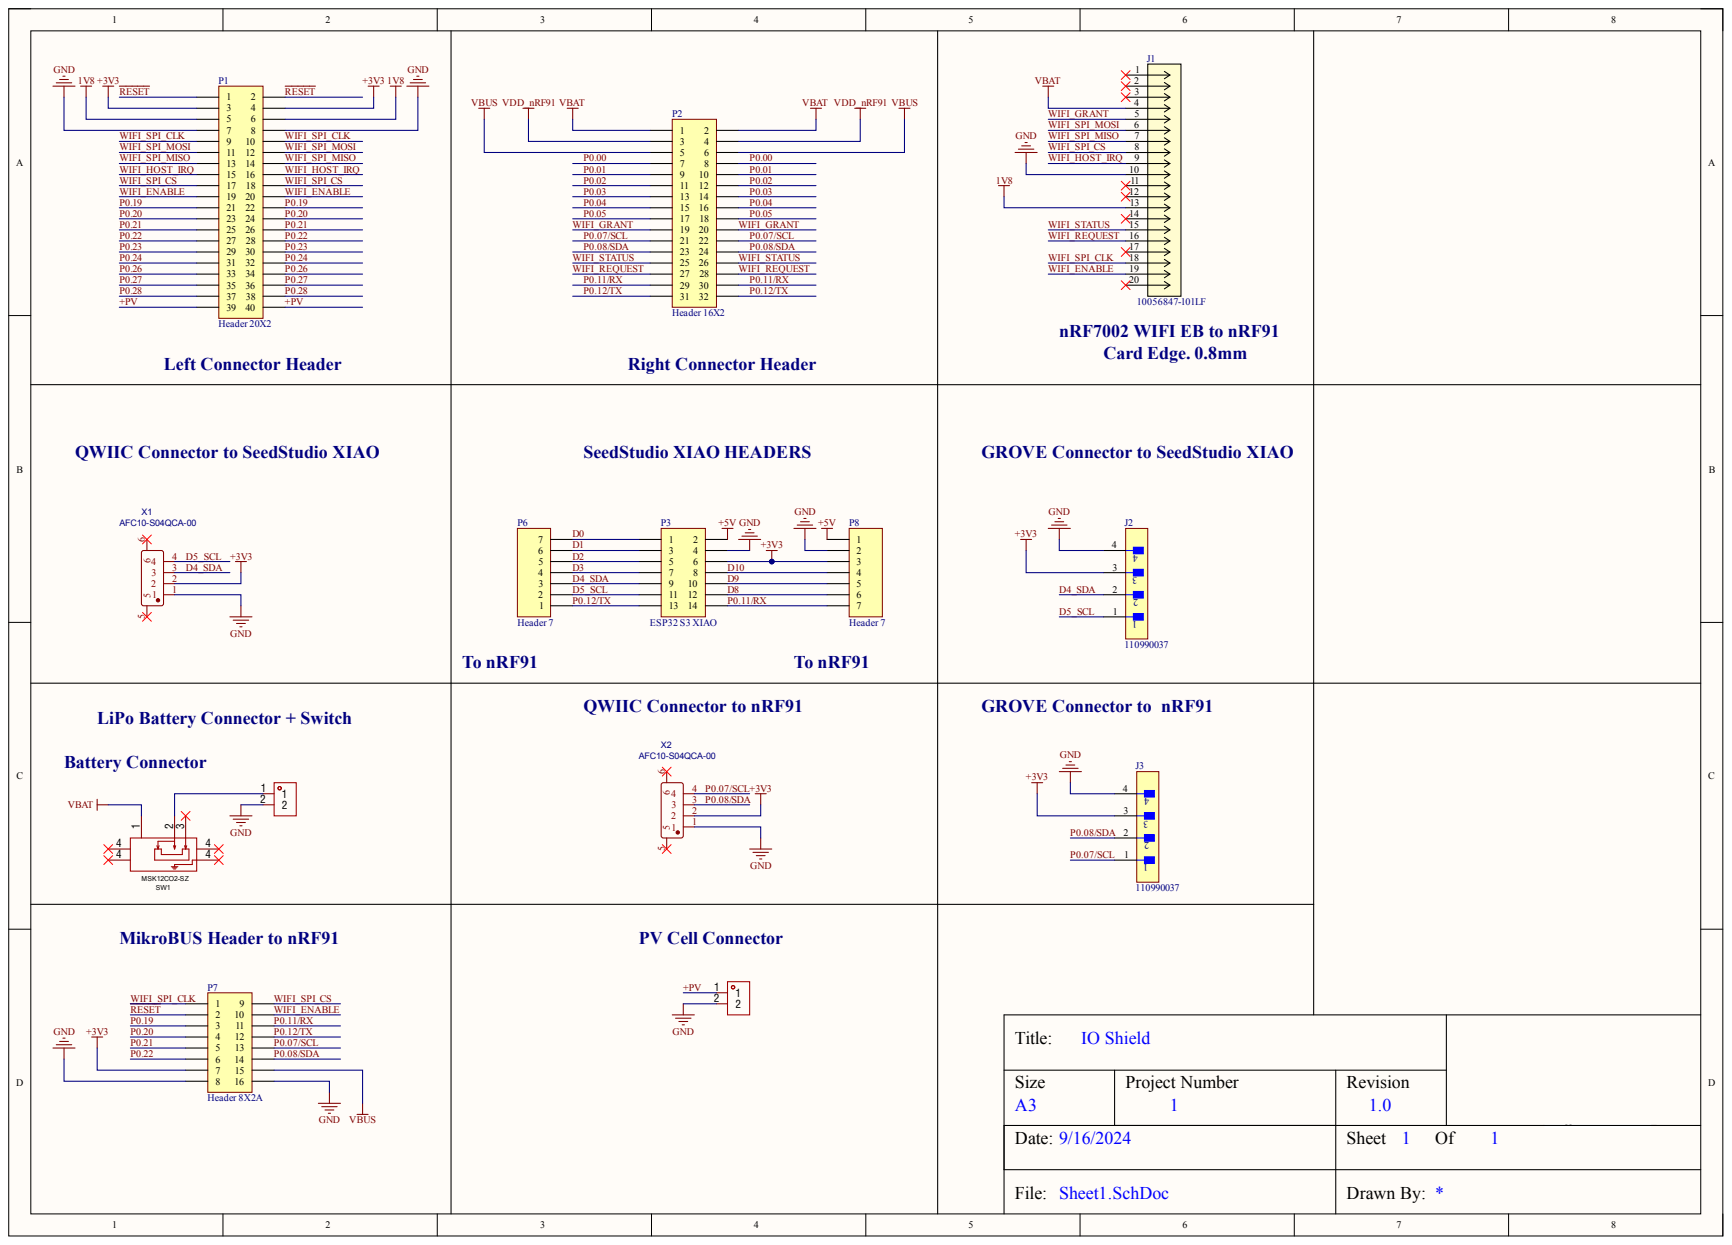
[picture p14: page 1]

WIFI_SPI_MISO | P0.00 P6 | P0.00 +5V P8
WIFI_HOST_IRQ | P0.01 | P0.01
WIFI_SPI_CS | P0.02 | P0.02
WIFI_ENABLE | P0.03 | P0.03
P0.19 | P0.04 | P0.04
P0.20 | P0.05 | P0.05
P0.21 | WIFI_GRANT | WIFI_GRANT
P0.22 | P0.07/SCL | P0.07/SCL
P0.23 | P0.08/SDA | P0.08/SDA
P0.24 | WIFI_STATUS | WIFI_STATUS
P0.26 | WIFI_REQUEST | WIFI_REQUEST
P0.27 | P0.11/RX | P0.11/RX
P0.28 | P0.12/TX | P0.12/TX
+PV | P3 | GND +5V GND

LiPo Battery Connector + Switch

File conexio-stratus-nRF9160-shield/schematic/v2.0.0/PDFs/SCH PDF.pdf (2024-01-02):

A

A

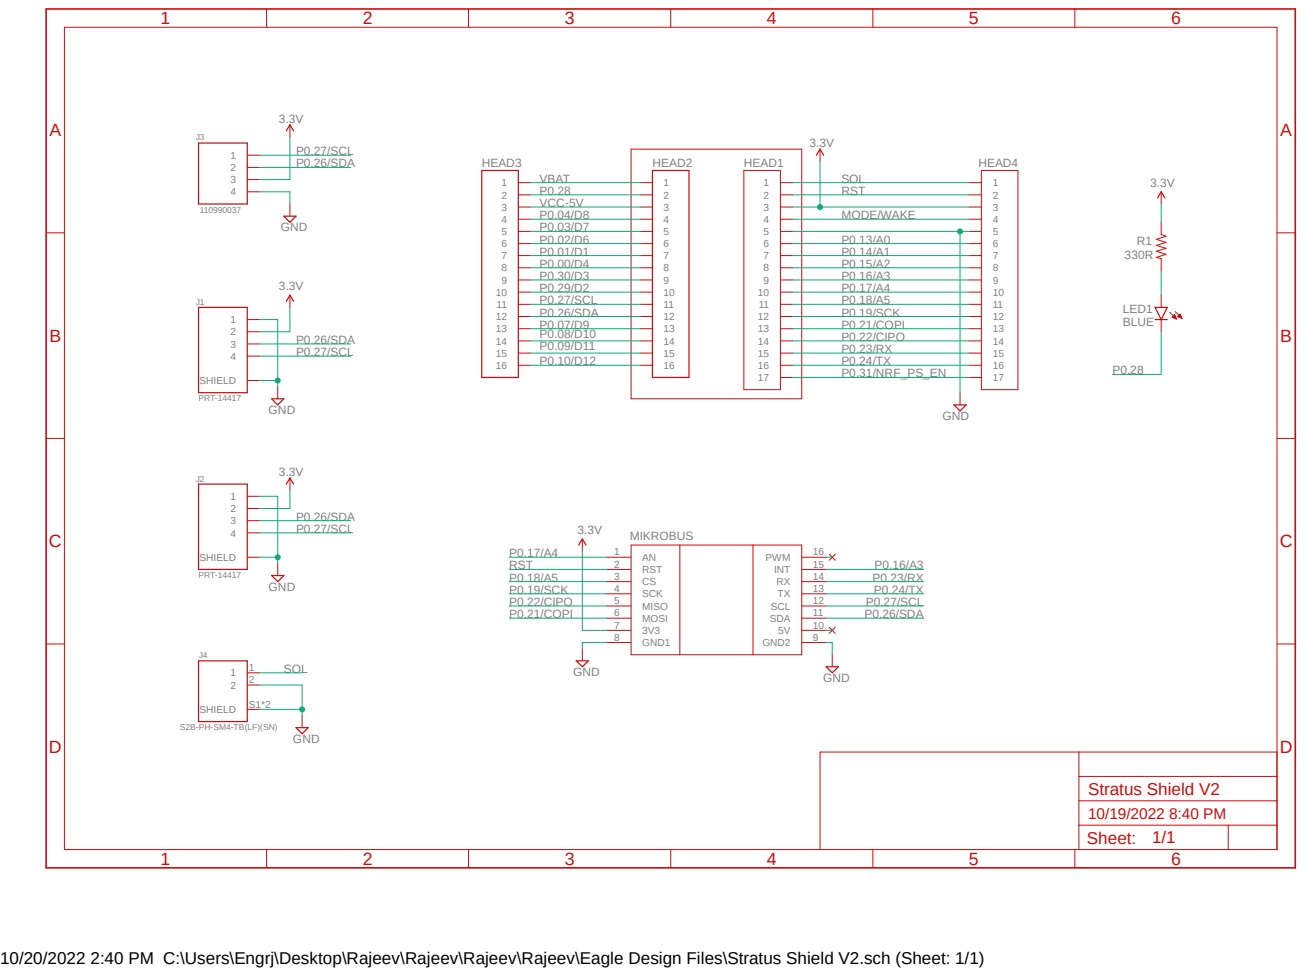
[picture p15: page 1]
BLUE; MIKROBUS; PRT-14417; GND; HEAD2; HEAD1; HEAD3; HEAD4; 2 SHIELD; LED1 AN 1; RST 2; SCK 4; MISO 5; MOSI 6; GND2; 9 PWM; INT; 13 SCL; 12 SDA; 10 GND1 8; 1 2 3 4 SHIELD; RST; P0.19/SCK; P0.27/SCL; P0.26/SDA; SOL; P0.21/COPI; P0.22/CIPO; MODE/WAKE; P0.31/NRF_PS_EN; VCC-5V; VBAT; Sheet:; Stratus Shield V2

10/20/2022 2:40 PM C:\Users\Engrj\Desktop\Rajeev\Rajeev\Rajeev\Rajeev\Eagle Design Files\Stratus Shield V2.sch (Sheet: 1/1)

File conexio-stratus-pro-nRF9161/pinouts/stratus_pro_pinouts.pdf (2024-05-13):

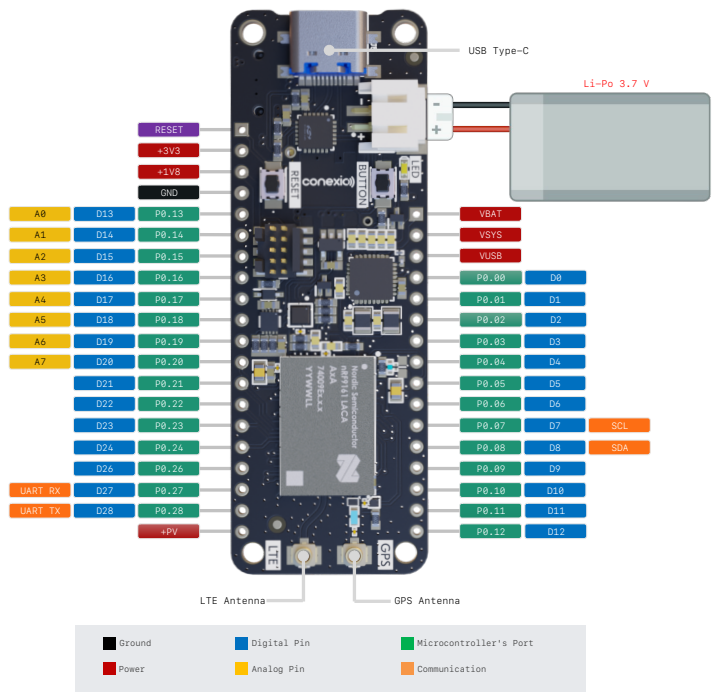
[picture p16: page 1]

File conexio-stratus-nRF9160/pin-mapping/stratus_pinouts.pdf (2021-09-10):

## Conexio Stratus

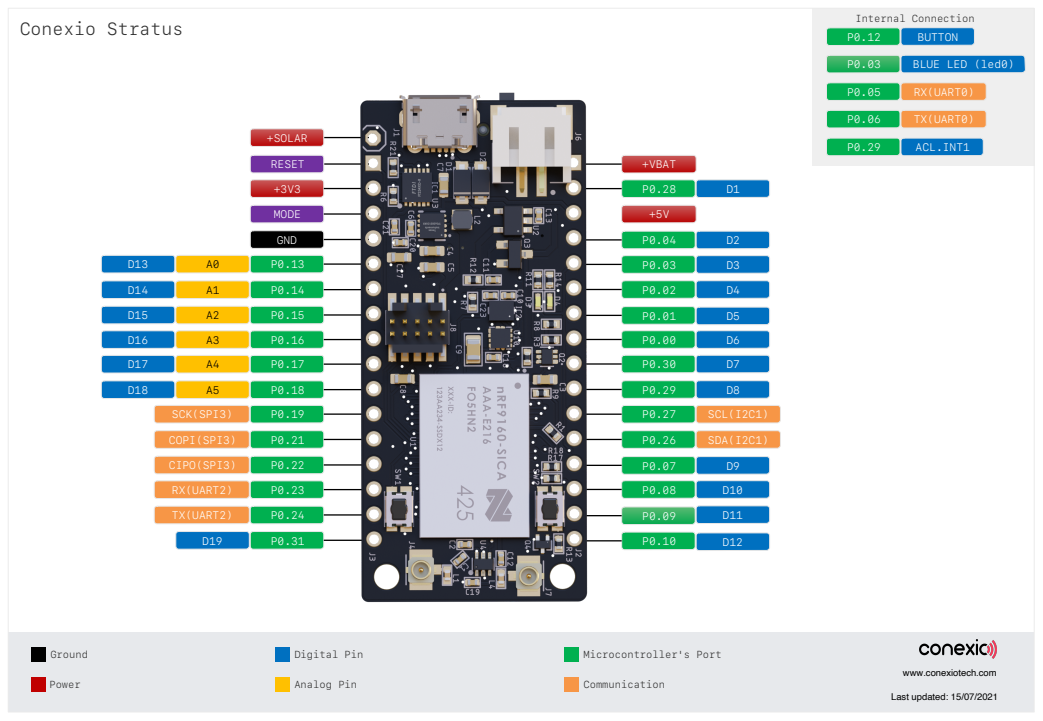
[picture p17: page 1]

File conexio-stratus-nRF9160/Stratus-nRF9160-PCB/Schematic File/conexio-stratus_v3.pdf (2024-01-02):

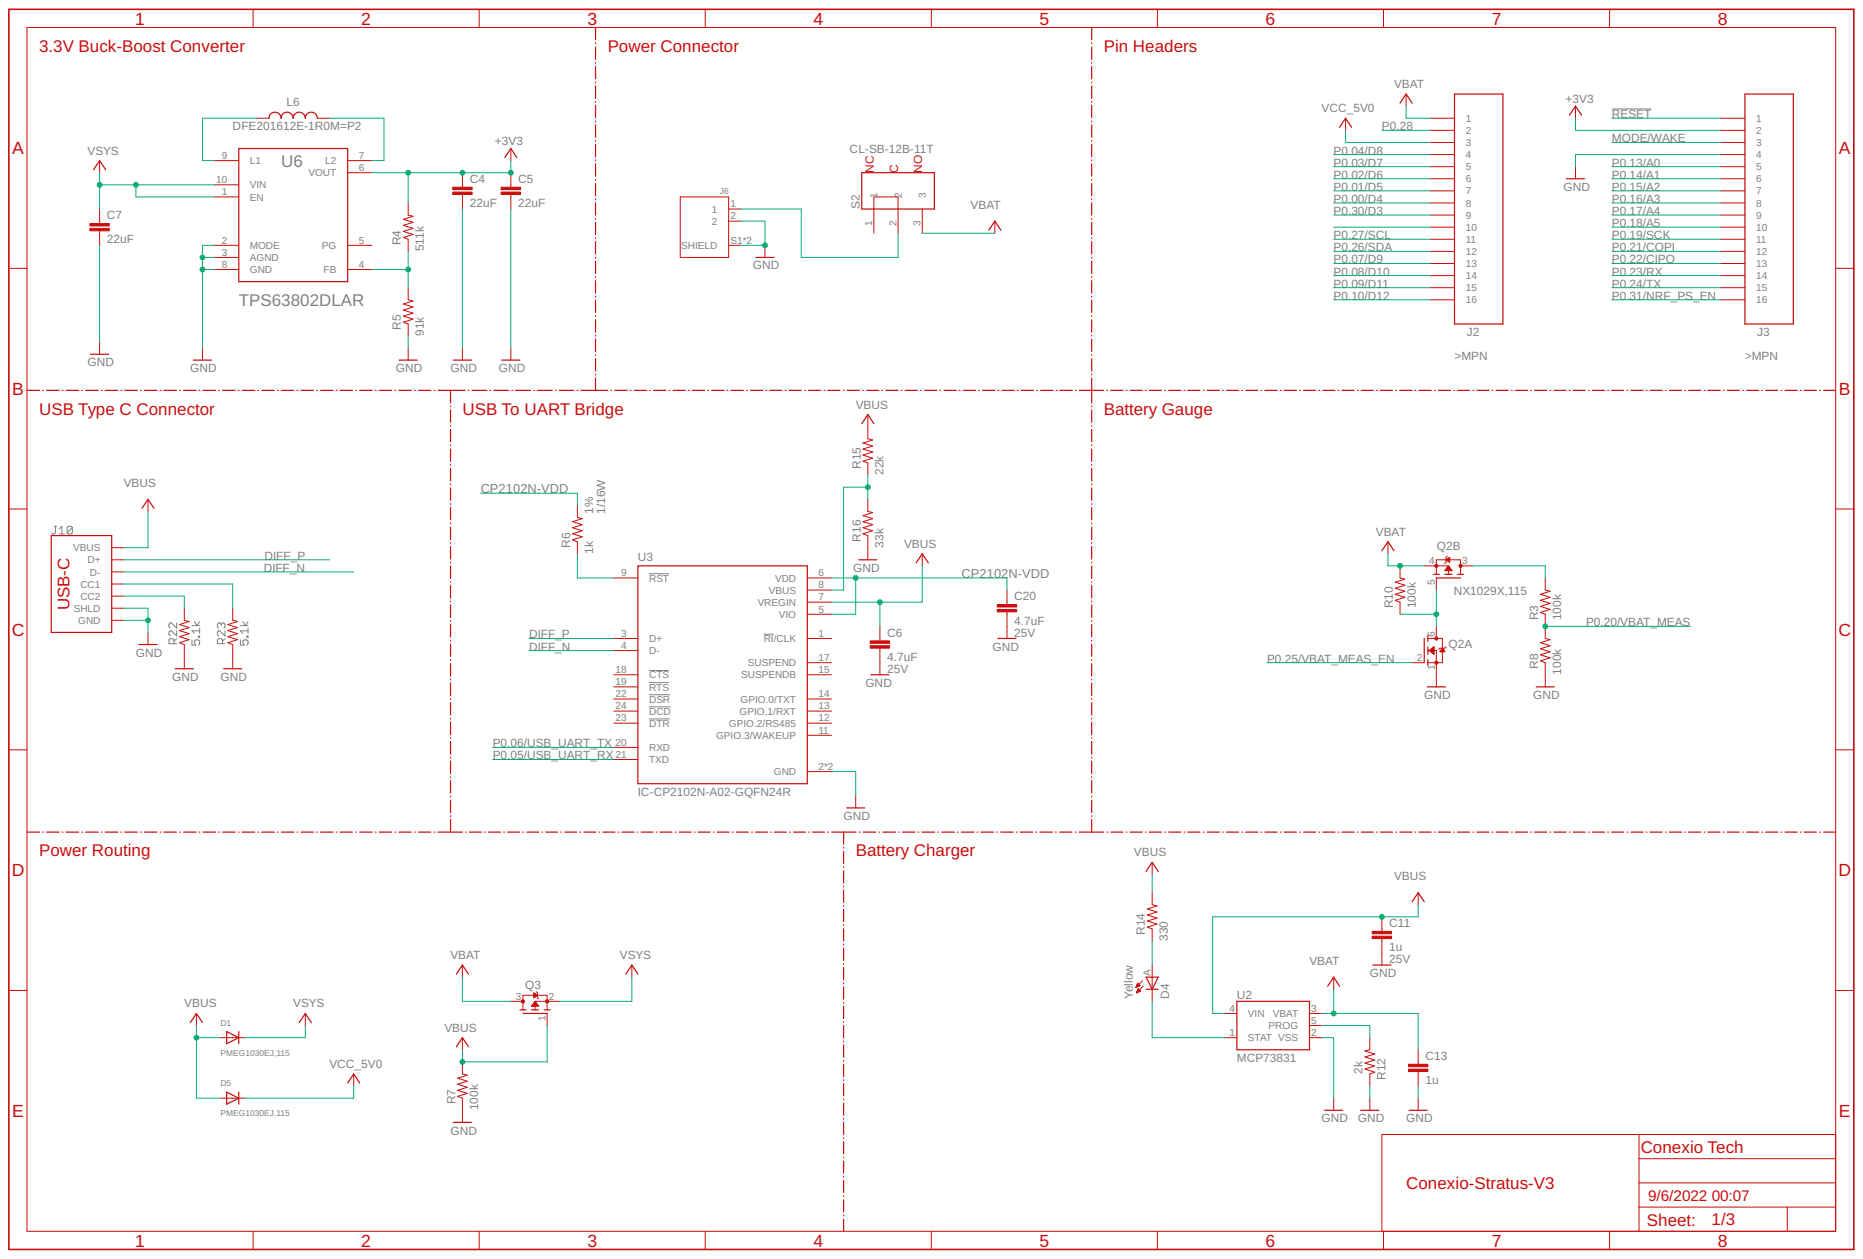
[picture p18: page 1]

Conexio Tech Conexio-Stratus-V3

Sheet:

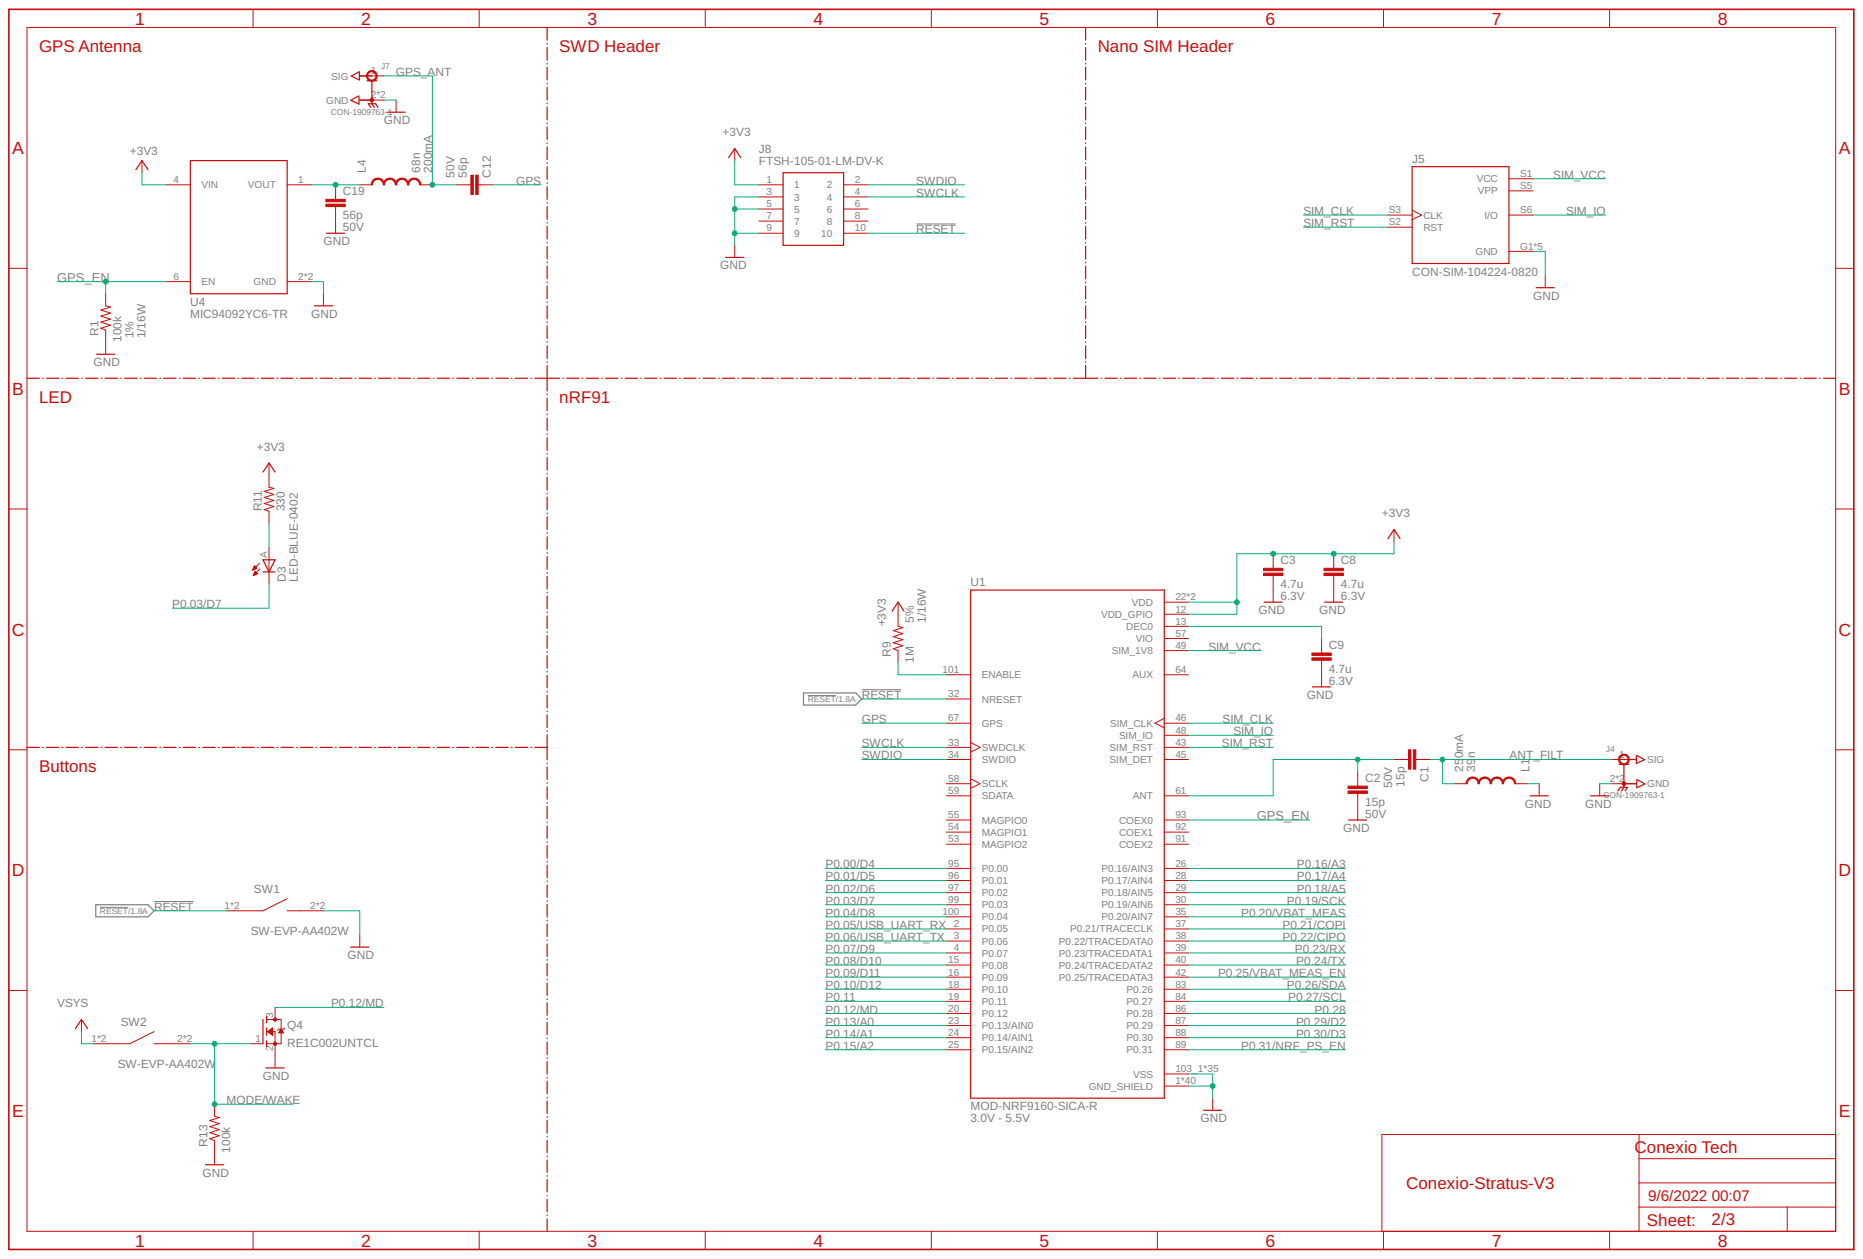
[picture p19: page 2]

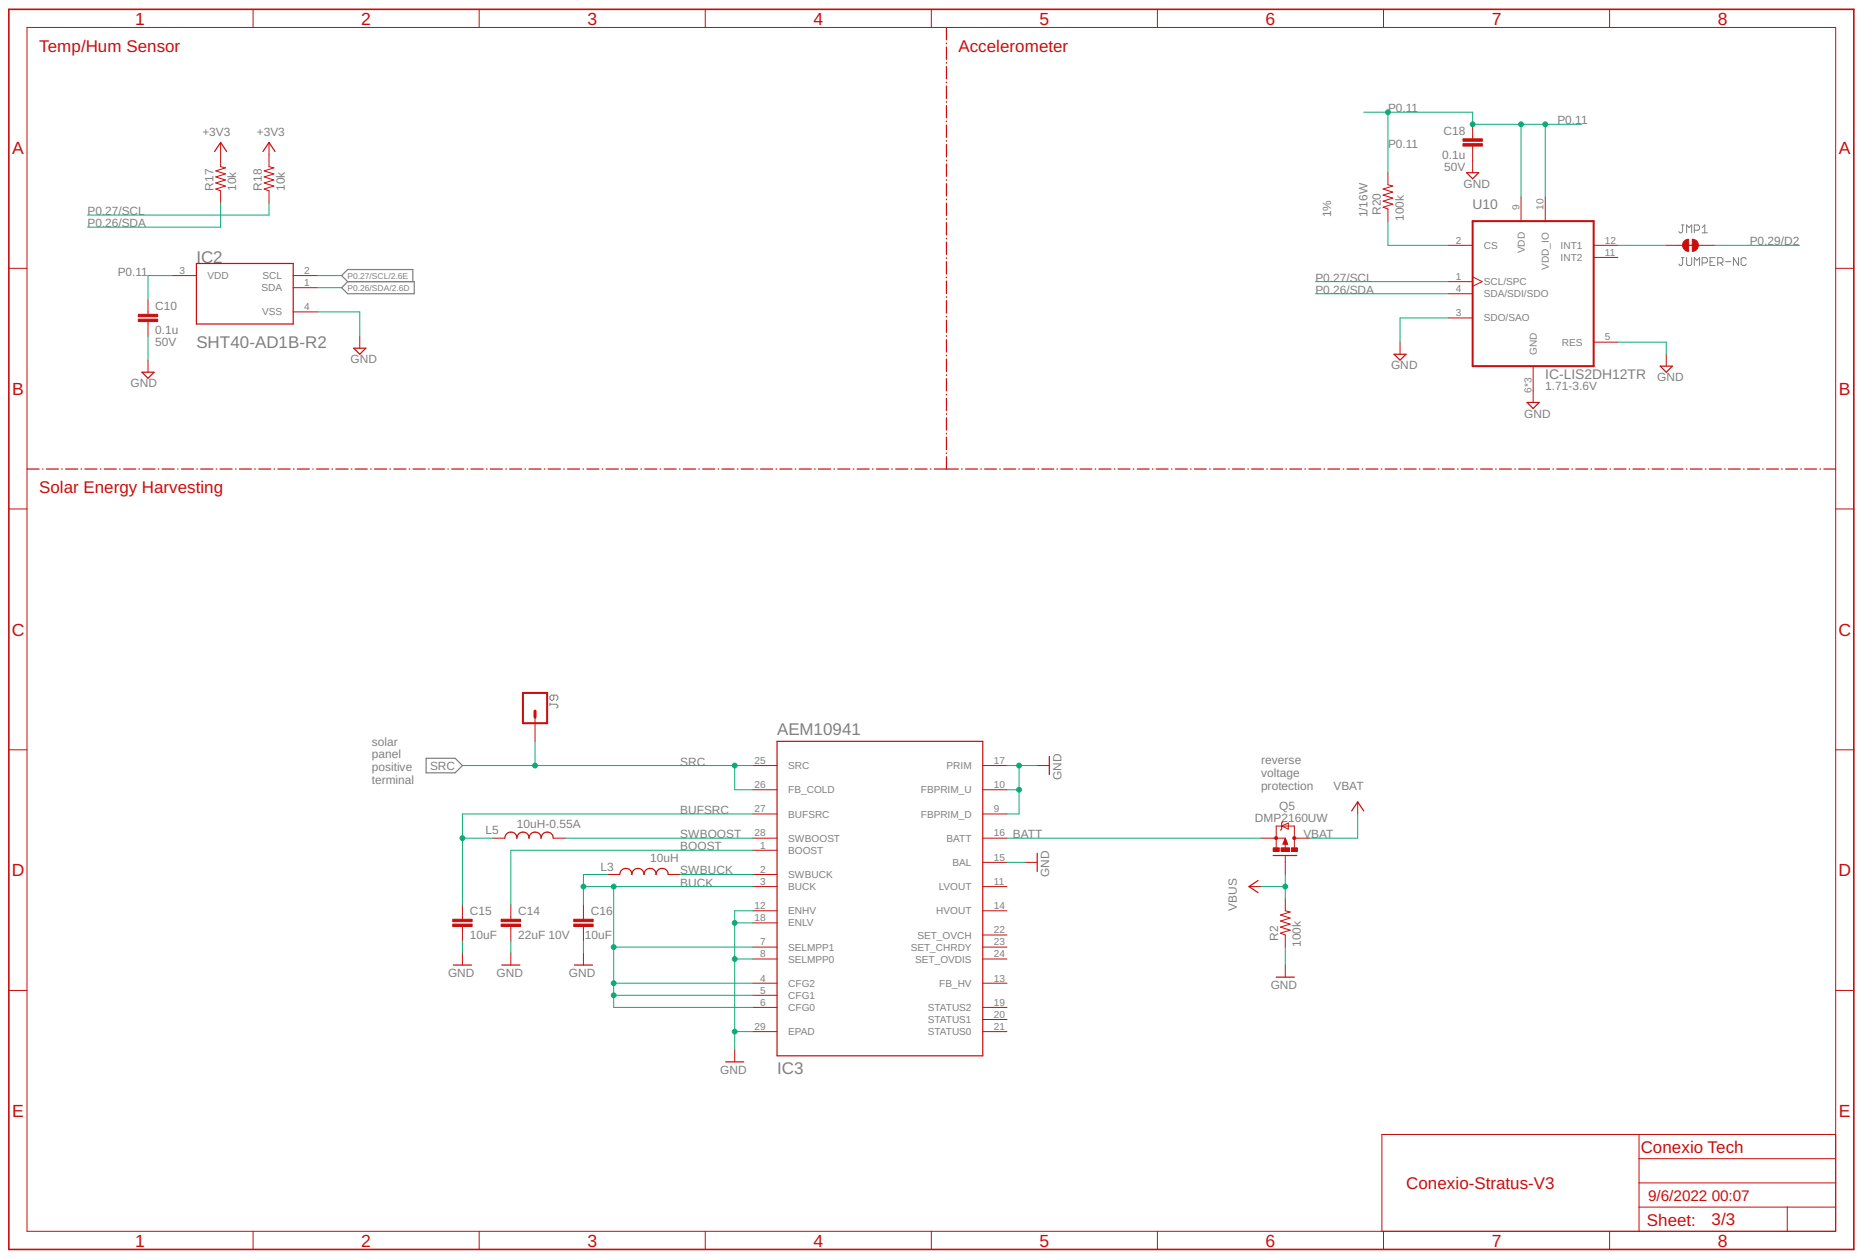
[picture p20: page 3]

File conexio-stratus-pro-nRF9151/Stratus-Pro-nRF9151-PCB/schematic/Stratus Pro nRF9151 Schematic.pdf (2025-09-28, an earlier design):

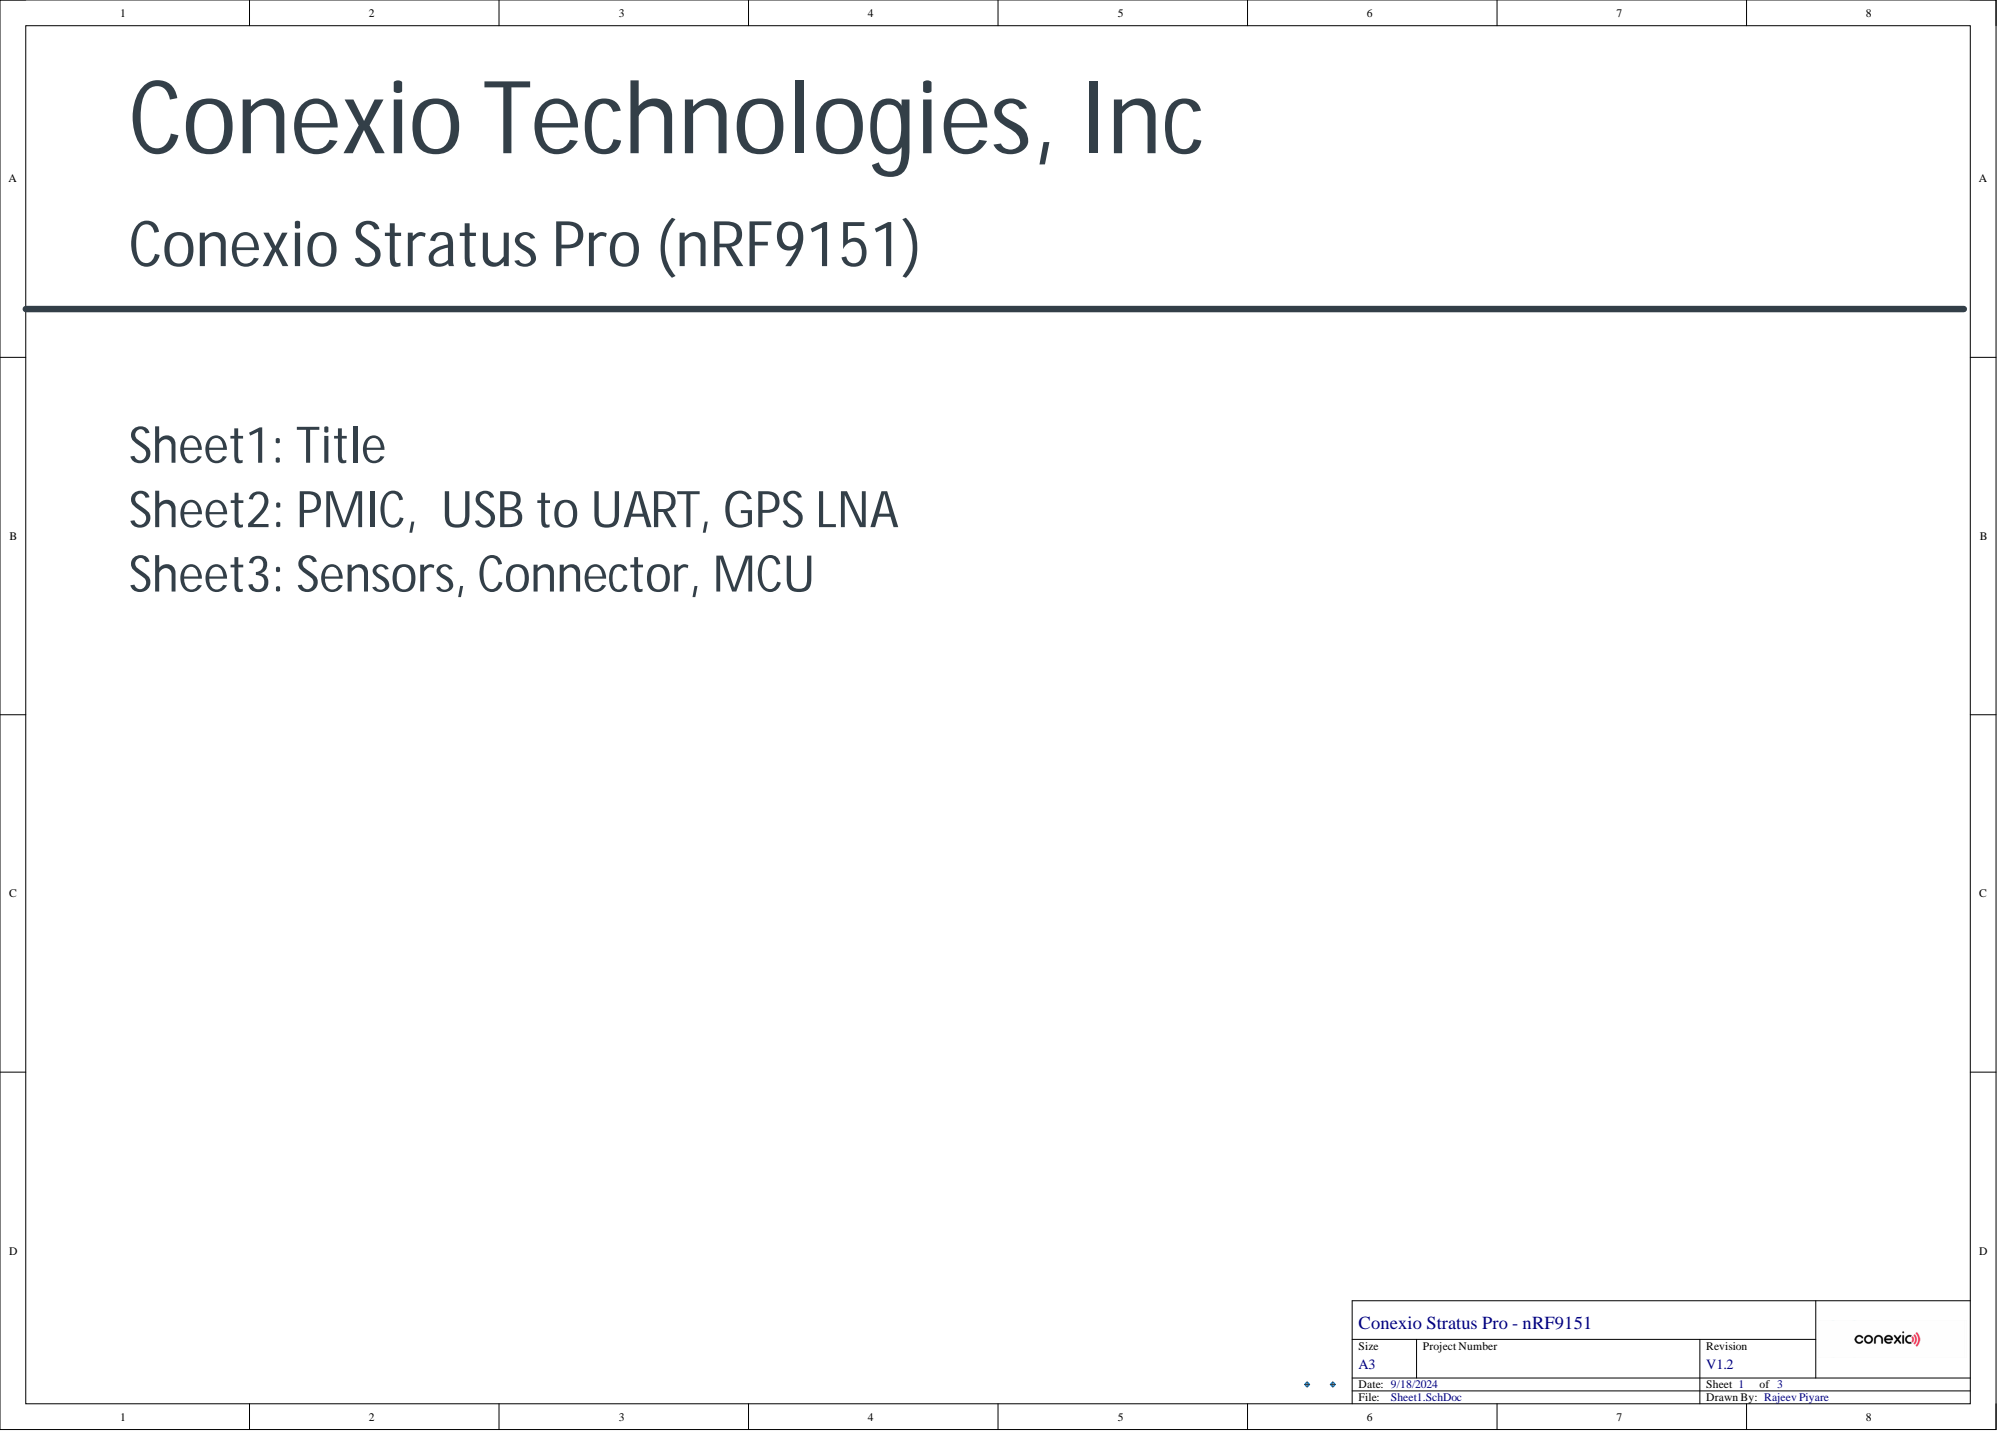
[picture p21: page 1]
Size; Project Number; Drawn By:; Rajeev Piyare; COFid1 COFid2

Conexio Technologies, Inc

Conexio Stratus Pro (nRF9151)

Sheet1: Title
Sheet2: PMIC, USB to UART, GPS LNA
Sheet3: Sensors, Connector, MCU

Conexio Stratus Pro - nRF9151

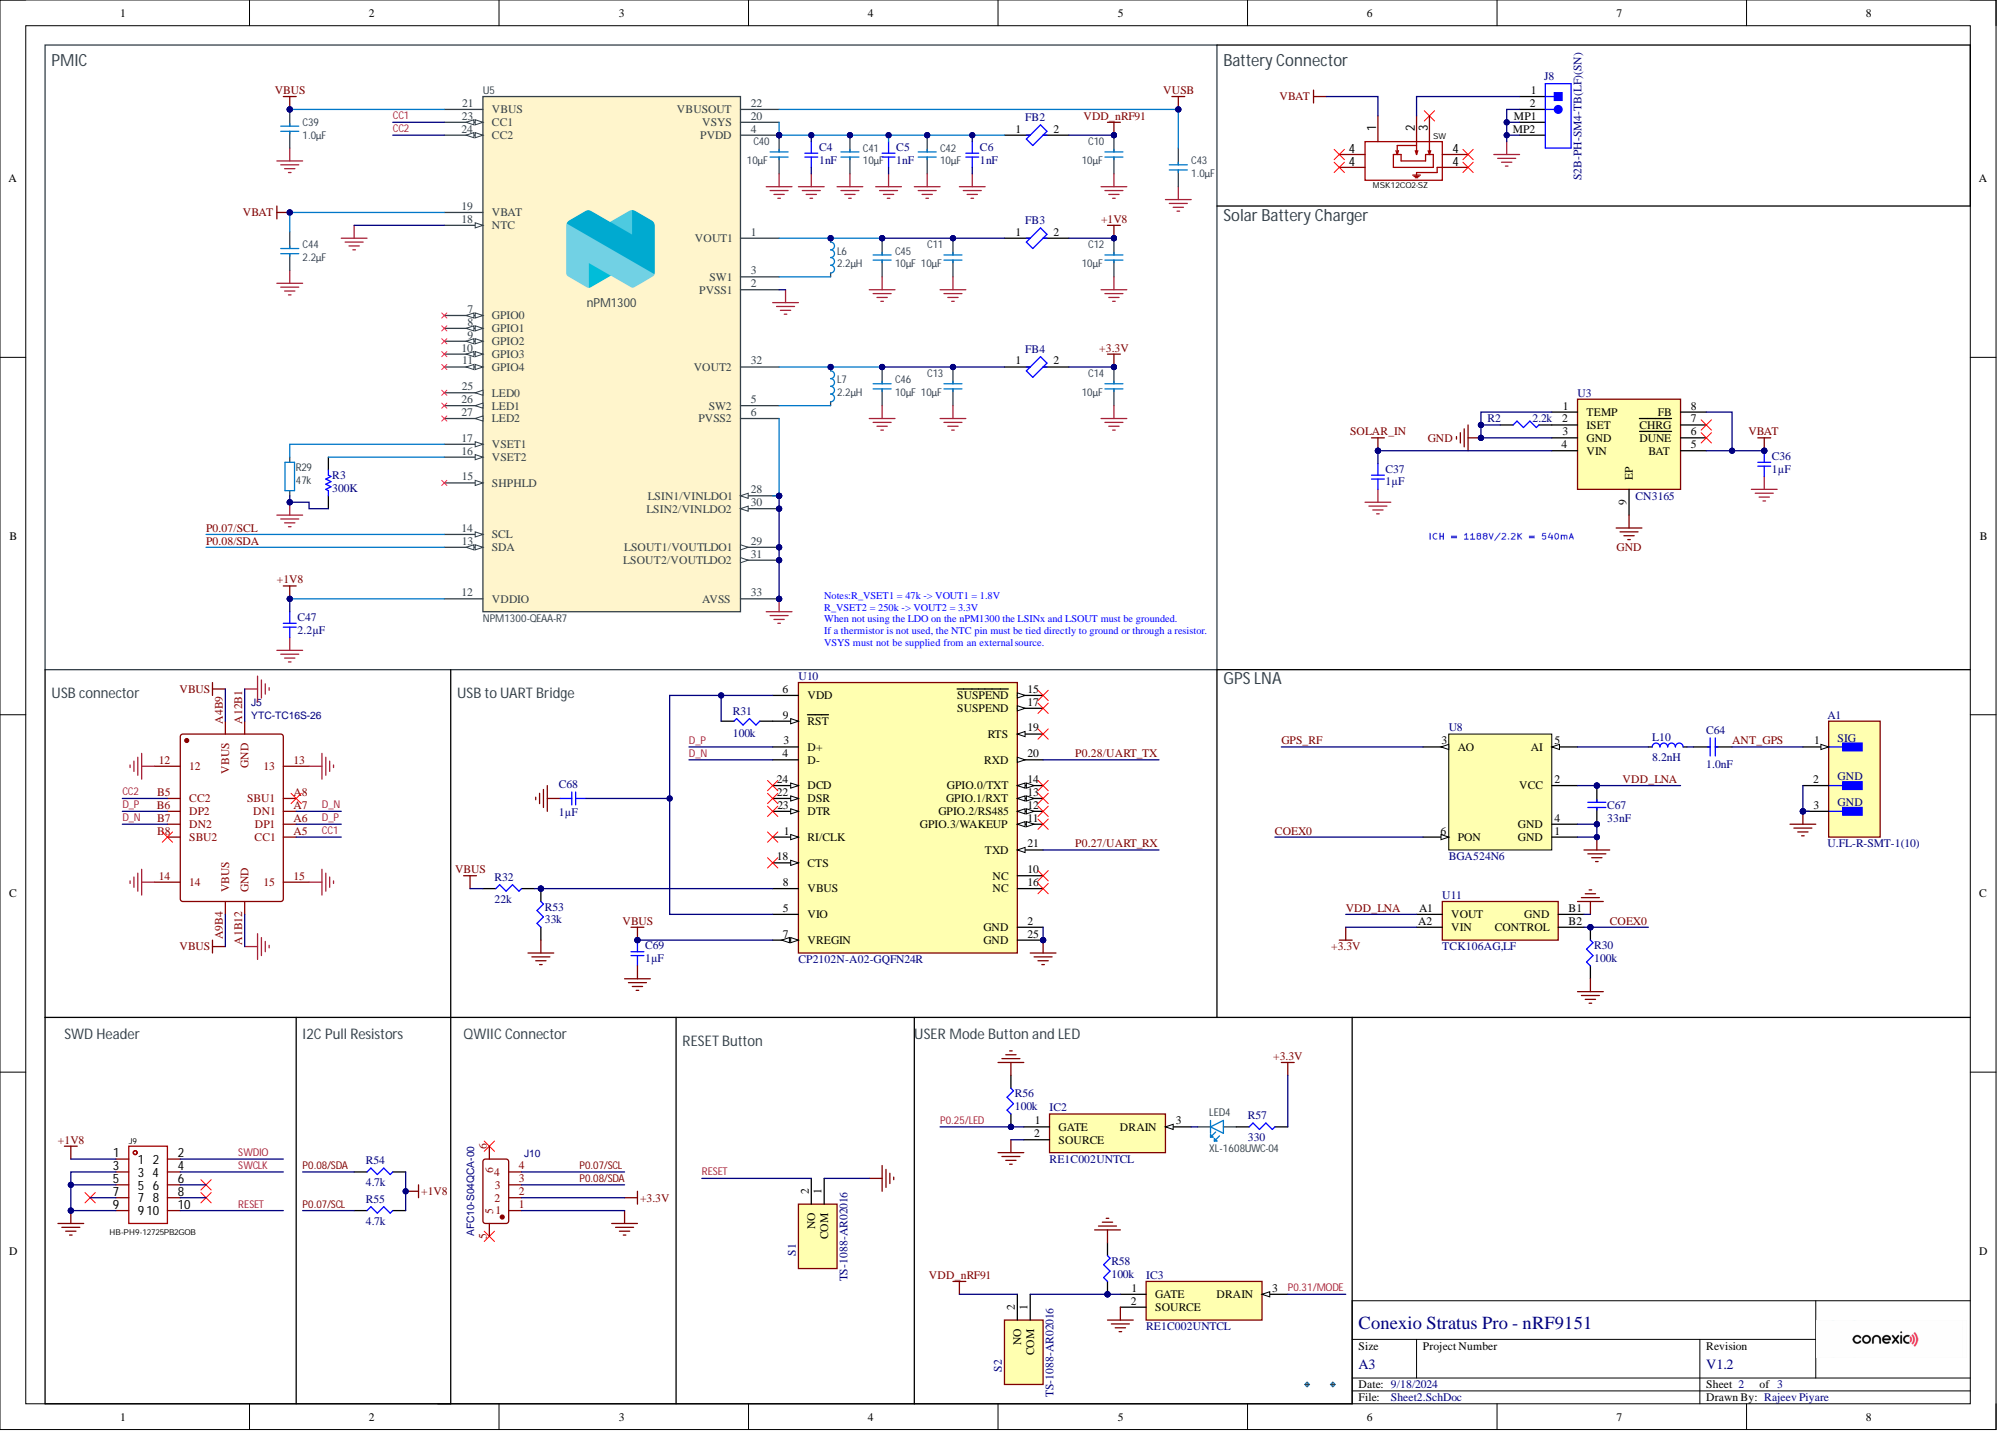
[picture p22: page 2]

Notes:R_VSET1 = 47k -> VOUT1 = 1.8V
R_VSET2 = 250k -> VOUT2 = 3.3V
When not using the LDO on the nPM1300 the LSINx and LSOUT must be grounded.
If a thermistor is not used, the NTC pin must be tied directly to ground or through a resistor.
VSYS must not be supplied from an externalsource.

USB to UART Bridge

USER Mode Button and LED


P0. 08/SDA | 4 3

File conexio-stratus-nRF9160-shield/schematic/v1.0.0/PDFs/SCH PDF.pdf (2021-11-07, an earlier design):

# SHIELD12341234

SHIELD ABCD | 1 | 2 | 3 | 4 | 5 | 6 | ABCD 1 | 2 | 3 | 4 | 5 | 6

SHIELD; CS 3 SCK 4 MISO 5 MOSI 6 3V3 7; GND2; PWM; INT; SCL; SDA; GND1 8 1234

AN 1 | 5V
RST 2 | 10


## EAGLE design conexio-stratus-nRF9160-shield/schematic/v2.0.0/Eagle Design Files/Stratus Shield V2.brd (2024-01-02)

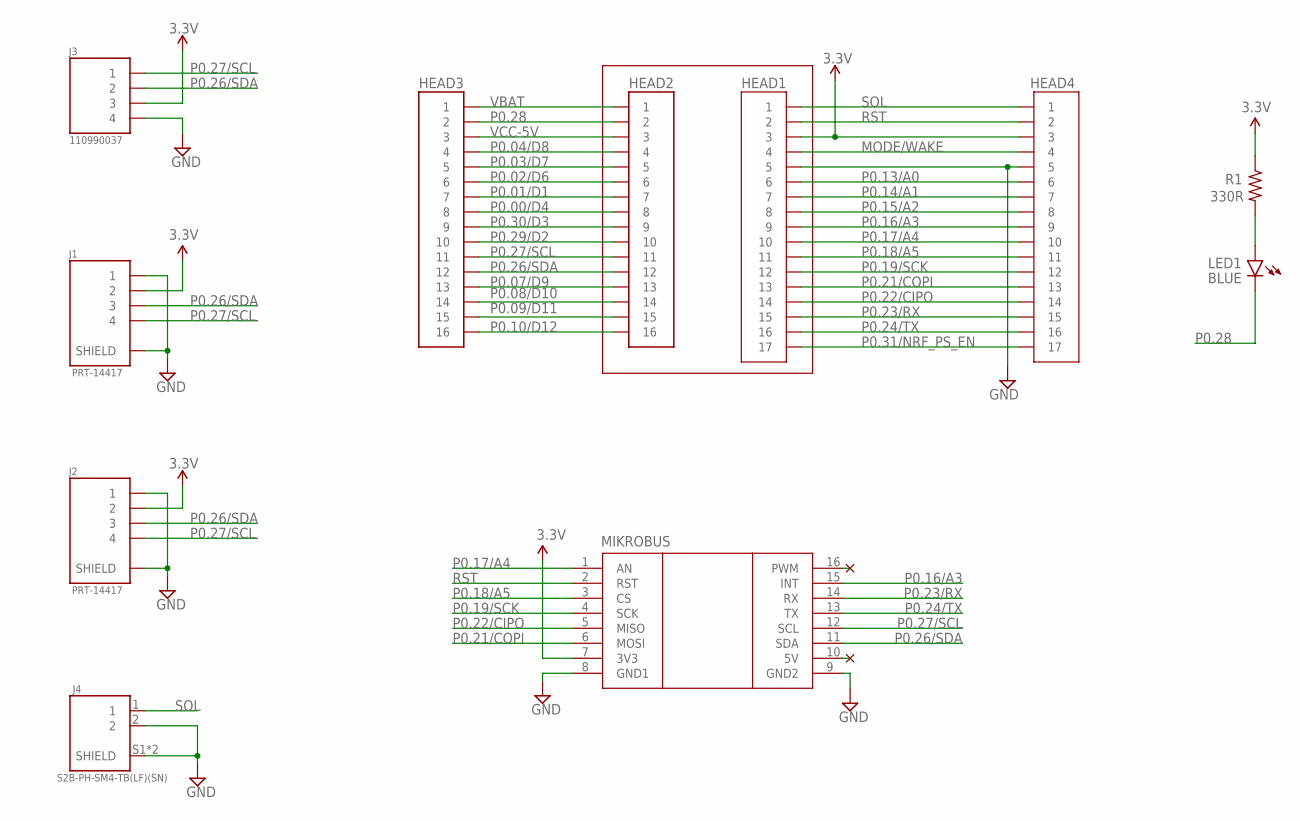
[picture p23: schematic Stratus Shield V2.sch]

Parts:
HEAD1, HEAD4: HEADER_16P; HEADER_16P2.54
HEAD2, HEAD3: SIP-12
J1, J2: PRT-14417; JST_SM04B-SRSS-TB(LF)(SN)
J3: 110990037; HW4-2.0-90D
J4: S2B-PH-SM4-TB(LF)(SN); JST_S2B-PH-SM4-TB(LF)(SN)
J11: MIKROBUS
LED1: BLUE; LED-0603
R1: 330R; R-0603

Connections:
3.3V: HEAD1.3, HEAD4.3, J1.2, J2.2, J3.3, J11.7 (3V3), R1.1
GND: HEAD1.5, HEAD4.5, J1.1, J1.S1 (SHIELD), J1.S2 (SHIELD), J2.1, J2.S1 (SHIELD), J2.S2 (SHIELD), J3.4, J4.2, J4.S1 (SHIELD), J4.S2 (SHIELD), J11.8 (GND1), J11.9 (GND2)
MODE/WAKE: HEAD1.4, HEAD4.4
unnamed: LED1.A, R1.2
P0.00/D4: HEAD2.8, HEAD3.8
P0.01/D1: HEAD2.7, HEAD3.7
P0.02/D6: HEAD2.6, HEAD3.6
P0.03/D7: HEAD2.5, HEAD3.5
P0.04/D8: HEAD2.4, HEAD3.4
P0.07/D9: HEAD2.13, HEAD3.13
P0.08/D10: HEAD2.14, HEAD3.14
P0.09/D11: HEAD2.15, HEAD3.15
P0.10/D12: HEAD2.16, HEAD3.16
P0.13/A0: HEAD1.6, HEAD4.6
P0.14/A1: HEAD1.7, HEAD4.7
P0.15/A2: HEAD1.8, HEAD4.8
P0.16/A3: HEAD1.9, HEAD4.9, J11.15 (INT)
P0.17/A4: HEAD1.10, HEAD4.10, J11.1 (AN)
P0.18/A5: HEAD1.11, HEAD4.11, J11.3 (CS)
P0.19/SCK: HEAD1.12, HEAD4.12, J11.4 (SCK)
P0.21/COPI: HEAD1.13, HEAD4.13, J11.6 (MOSI)
P0.22/CIPO: HEAD1.14, HEAD4.14, J11.5 (MISO)
P0.23/RX: HEAD1.15, HEAD4.15, J11.14 (RX)
P0.24/TX: HEAD1.16, HEAD4.16, J11.13 (TX)
P0.26/SDA: HEAD2.12, HEAD3.12, J1.3, J2.3, J3.2, J11.11 (SDA)
P0.27/SCL: HEAD2.11, HEAD3.11, J1.4, J2.4, J3.1, J11.12 (SCL)
P0.28: HEAD2.2, HEAD3.2, LED1.K (C)
P0.29/D2: HEAD2.10, HEAD3.10
P0.30/D3: HEAD2.9, HEAD3.9
P0.31/NRF_PS_EN: HEAD1.17, HEAD4.17
RST: HEAD1.2, HEAD4.2, J11.2 (RST)
SOL: HEAD1.1, HEAD4.1, J4.1
VBAT: HEAD2.1, HEAD3.1
VCC-5V: HEAD2.3, HEAD3.3

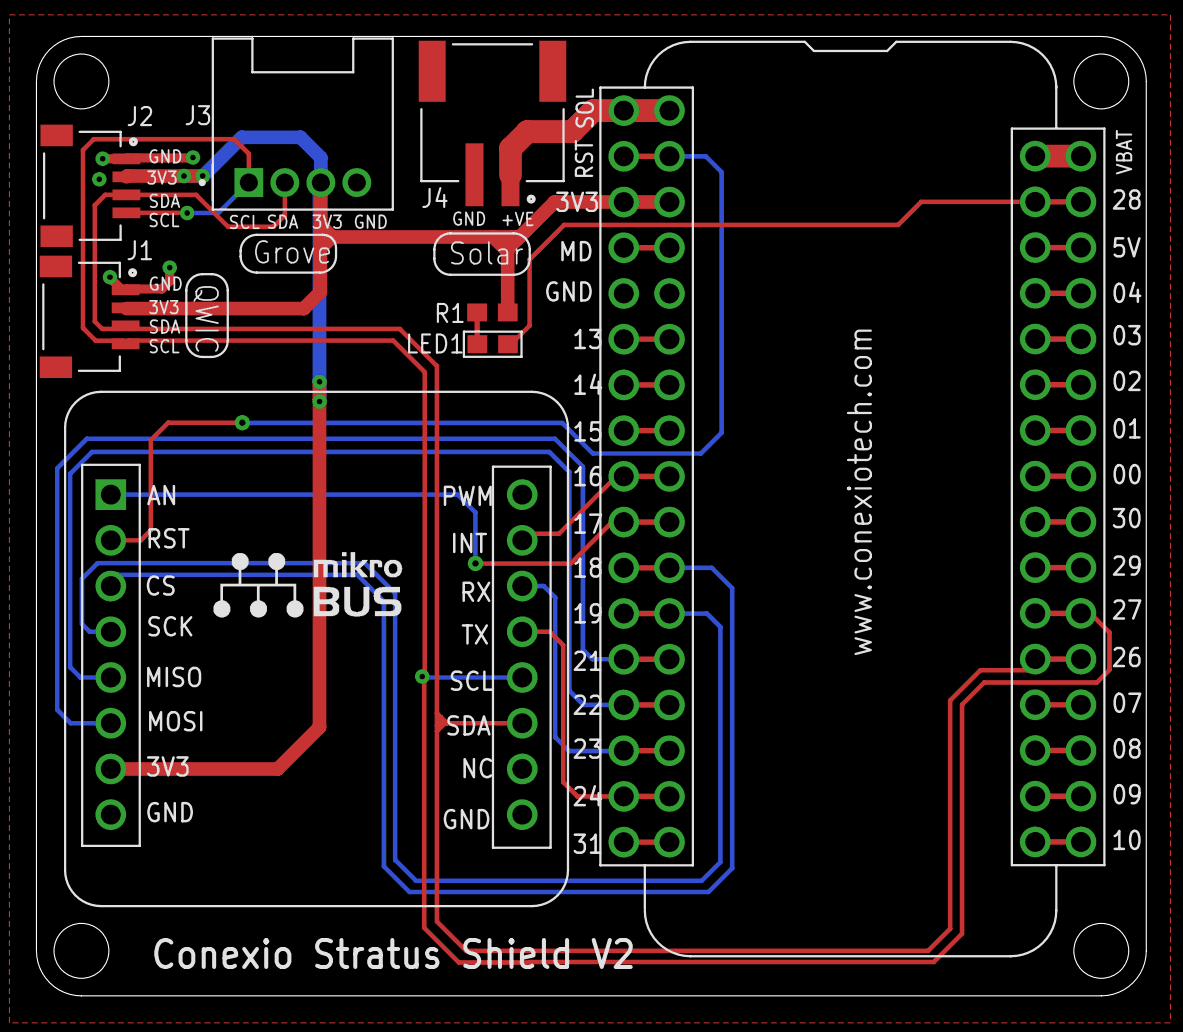
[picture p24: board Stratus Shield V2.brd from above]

Board: 2 copper layers, 61.7 x 53.3 mm, 12 parts (1 on the bottom side), 34 nets.

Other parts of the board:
U$1: ROHS_LOGO_0.18_IN

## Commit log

2021-09-10 add board pinouts diagram
2021-11-07 add conexio stratus shield schematics and license file *released under the CERN Open Hardware Licence Version 2
    [Grove Shield.brd, Grove Shield.sch]
2024-01-02 add conexio stratus nRF9160 PCB files
    [drill_1_16.xln]
2024-01-02 add stratus shield PCB design files
    [Shield_v2_BOM.xlsx, Stratus Shield V2.brd, Stratus Shield V2.sch]
2024-05-13 add Stratus Pro nRF9161 PCB resources
2024-07-16 stratus pro pcb desig files
2025-02-22 add latest board files, pinouts, images
    [BOM Expansion Doc.xlsx, Pick Place for PCB.csv, Pick Place for PCB1.csv]
2025-02-22 rename board directories
    [Grove Shield.brd, Grove Shield.sch, Shield_v2_BOM.xlsx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]
2025-09-28 add Stratus Pro nRF9151 schematics
2026-06-07 add nRF9151 v1.4 hardware files
    [3D Model.step]

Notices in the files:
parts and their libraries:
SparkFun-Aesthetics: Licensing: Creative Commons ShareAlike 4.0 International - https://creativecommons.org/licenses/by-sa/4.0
